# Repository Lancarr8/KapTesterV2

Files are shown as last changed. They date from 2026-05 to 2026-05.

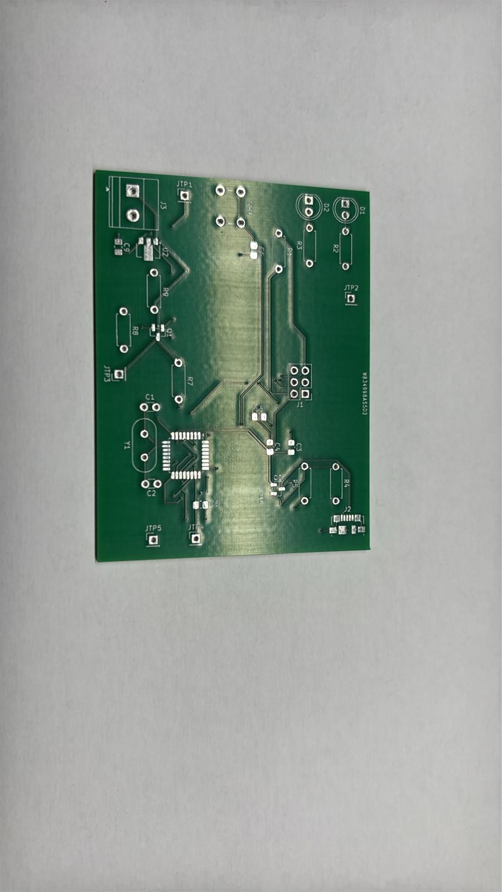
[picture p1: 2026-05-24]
Dokumente/Phasen/Durchführung/Fotos V1/V1_Leer_Front.jpeg

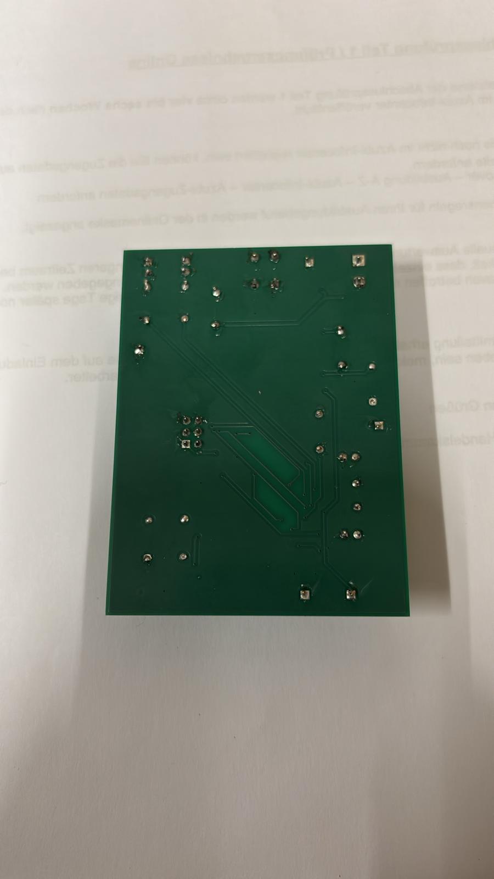
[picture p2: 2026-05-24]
Dokumente/Phasen/Durchführung/Fotos V1/V1_Back_Best.jpeg

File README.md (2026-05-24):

# ⚡ KapTester V2

> Capacitance Tester — ATmega328P based custom PCB project  
> Built as **AP2 (Abschlussprüfung Teil 2)** — Vocational exam project 🇩🇪







---

## 📷 Photos
*Coming soon – V2 build photos*

---

## 📖 About

The **KapTester V2** is a custom-built capacitance measurement device based on the ATmega328P microcontroller. It was designed and built from scratch as part of a vocational training exam (IHK AP2), covering all phases from schematic design to PCB manufacturing and firmware development.

---

## ⚙️ Hardware

| Component | Details |
|---|---|
| MCU | ATmega328P @ 16MHz |
| Display | SSD1306 OLED 128x64 (I2C) |
| Voltage Reg | LM317 (1.2V – 32V adjustable) |
| PCB | Custom 2-layer, manufactured by PCBWay |
| Power | USB (5V) |
| Interface | Tactile button, screw terminals |

---

## 💾 Firmware

Three firmware versions were developed during the project:

| Version | Folder | Description |
|---|---|---|
| FW1 | `fw1_produktion` | Production firmware – stable release |
| FW2 | `fw2_test` | Test firmware – debugging & measurement testing |
| FW3 | `fw3_Voll` | Full feature firmware – all functions enabled |

### 🔧 Flashing

```bash
# Flash production firmware via avrdude
avrdude -c usbasp -p m328p -U flash:w:fw1_produktion/kaptester.hex:i
```

---

## 📁 Repository Structure

```
KapTesterV2/
├── Firmware/
│   ├── fw1_produktion/     # Production firmware (main.c, .hex, .elf)
│   ├── fw2_test/           # Test firmware
│   └── fw3_Voll/           # Full firmware
├── KiCad KapTester V2/
│   ├── KapTesterV2.kicad_sch   # Schematic
│   ├── KapTesterV2.kicad_pcb   # PCB layout
│   └── GerberV2/               # Gerber files for manufacturing
├── Dokumente/              # Project documentation (German)
│   └── Phasen/             # Phase documentation (Info/Plan/Build/Evaluate)
└── Präsentation/           # Final exam presentation (PPTX + PDF)
```

---

## 🛠️ Tools Used

- **AVR-GCC** – Firmware compilation
- **avrdude** – Flashing
- **KiCad 8** – Schematic & PCB design
- **PCBWay** – PCB manufacturing

---

## 📄 License

MIT License – feel free to use, modify and build upon this project.

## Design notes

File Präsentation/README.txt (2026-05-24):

Infos für Vorstellung

Vorteile gegenüber DMM

Messbereich (viele DMMs messen nur bis 200 µF oder max. 2.000 µF – für 10.000 µF-Elkos reicht das nicht), 

Messgeschwindigkeit (ein DMM braucht bei großen Elkos 30+ Sekunden und gibt oft keinen stabilen Wert – dein Gerät hat einen deterministischen Ablauf mit max. 15 s Timeout),

Sicherheit (automatischer Entladepfad, Verpolschutz, dediziertes Gerät für diese Aufgabe). Der KapTester ist ein schnelles Werkstatt-Prüfmittel für grobe Pass/Fail-Entscheidungen – kein Präzisionsgerät.

Eingangsspannung Facts

Micro-USB ist weit verbreitet, jeder hat ein passendes Kabel

Durch die Bauform ist eine Verpolung beim Einstecken nicht möglich

D+/D−-Datenleitungen sind bei mir no-connect – ich nutze den USB-Anschluss ausschließlich als Spannungsversorgung.

5V USB ist ein standardisierter Pegel, der alle Komponenten meiner Schaltung versorgen kann. 
(Der ATmega328P arbeitet von 1,8V bis 5,5V, der LM317L braucht mindestens ~2,5V Eingangsspannung um seinen Dropout zu überwinden, und das OLED läuft auf 3,3–5V. USB liefert bis zu 500 mA – meine Schaltung braucht maximal ~50 mA, also mehr als ausreichend)

Nach der 5V Eingangsspannung ->  Q1 – der PMOS Verpolschutz

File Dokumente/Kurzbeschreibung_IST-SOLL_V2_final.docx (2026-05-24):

Kurzbeschreibung des betrieblichen Auftrags und der Anlage

Kapazitätstester (KapTester V2) │ AP2 2026

Projektbezeichnung | Kapazitätstester – Betrieblicher Auftrag AP2
Azubi / Ersteller | Nico Schmidt
Ausbildungsberuf | Elektroniker für Geräte und Systeme
Bearbeitungszeitraum | März 2026 – Mai 2026
Dokumentversion | V2.0 │ Stand 26.04.2026

1 IST-Zustand und SOLL-Zustand

IST-Zustand (Problem) | SOLL-Zustand (Ergebnis)
Fehlende Prüfmöglichkeit im Werkstattbetrieb: Elektrolytkondensatoren lassen sich nicht schnell auf Kapazitätswert prüfen. Handelsübliche Multimeter sind im Bereich > 1.000 µF ungenau oder fehlen. Beim Umgang mit geladenen Großkondensatoren (bis 10.000 µF) besteht Sicherheitsrisiko durch Restladung und Verpolung. Kein dediziertes Prüfmittel im Ausbildungsbetrieb vorhanden. | Eigenentwickelter Kapazitätstester (Prototyp V2): Messbereich 10 µF – 10.000 µF · Genauigkeit ±20 % Messprinzip: Konstantstromladung (LM317L, 1,042 mA) + ATmega328P-AU ADC mit interner 1,1-V-Referenz Schutz: PMOS Verpolschutz (IRLML6402, Gate 1 MΩ/100 kΩ) + gesteuerter Entladepfad (2N7002 + 470 Ω) Anzeige: 2 LEDs (OK/Fehler) + OLED SSD1306 (I²C) Platine: 2-lagig, 90×70 mm, PCBWay, Hybrid THT/SMD

2 Abgrenzung (Nicht-Ziele)

· Keine ESR-Messung (Äquivalent Series Resistance)

· Keine Leckstrommessung als eigener Messwert

· Kein Gehäuse – Prototyp als nackte Leiterplatte

· Keine Kalibrierung mit externem Referenznormal

· Kein serieller Ausgang (UART/USB-CDC)

KapTester V2 · Nico Schmidt · IHK Osnabrück · AP2 2026

Dokumentenübersicht – Anlagen zur Dokumentation

Nr. | Phase | Anlage | Zweck / Inhalt
1 | Information | Lastenheft V2.0 | Anforderungen, Funktionsumfang, Abnahmekriterien
2 | Information | Blockschaltbild (draw.io) | Systemarchitektur, Signal- und Messpfad
3 | Information | Schaltplanauszug V2 (KiCad PDF) | Vollständiger Stromlaufplan, Netze, Bauteilwerte
3,5 | Information | Techn. Schaltungsbeschreibung | Technische Schaltungsbeschreibung (Zusatz)
4 | Planung | Ablaufplan (Schritte 1–21) | Zeitplanung, Vorgehen, Meilensteine
5 | Planung | Bauteilauswahl / BOM V2 | Materialbestellung, Footprints, Lieferanten
6 | Planung | Schnittstellentabelle V2 | Alle Stecker, Testpunkte, Netzzuordnung
7 | Planung | Risikoanalyse (R1–R6) | Risiken und Gegenmaßnahmen
8 | Durchführung | Löt- und Montageprotokoll | Bestückungsreihenfolge, Nacharbeit
9 | Durchführung | Fotos Bestückung V2 | Bildnachweis Lötergebnis
10 | Bewertung | Inbetriebnahmeprotokoll | Spannungen, Ströme, Erstfunktion
11 | Bewertung | Messprotokoll | 5 Referenzkondensatoren ±20 %-Nachweis
12 | Bewertung | Abnahmeprotokoll | Übergabe, Testfälle abgehakt
13 | Bewertung | Bedienungsanleitung | Benutzerführung, Sicherheitshinweise
14 | Extras | Datenblätter, eigene Dokumente | Datenblätter, eigene Dokumente

KapTester V2 · Nico Schmidt · IHK Osnabrück · AP2 2026

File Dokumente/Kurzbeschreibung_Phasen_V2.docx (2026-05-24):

Kurzbeschreibung der Phasen

KapTester V2 │ AP2 2026 │ Nico Schmidt

Dieser Abschnitt beschreibt die vier Projektphasen (Information, Planung, Durchführung, Bewertung) des betrieblichen Auftrags AP2 – Kapazitätstester V2.

Phase 1: Information

In der Informationsphase wurden die Anforderungen des Auftrags aufgenommen und das technische Konzept erarbeitet. Ausgangspunkt war der Bedarf im Ausbildungsbetrieb: Elektrolytkondensatoren bis 10.000 µF sollen schnell und sicher auf ihre Kapazität geprüft werden können, ohne dass ein teures Laborgerät erforderlich ist.

Das Messprinzip wurde auf Basis verfügbarer Bauteile gewählt: Konstantstromladung mit dem LM317L (I = 1,042 mA) und anschließende ADC-Zeitmessung durch den ATmega328P-AU mit interner 1,1-V-Referenz. Dieses Verfahren liefert bei konstantem Strom eine lineare Spannungsrampe am Kondensator, woraus die Kapazität direkt berechnet werden kann: C = I × t / U.

Parallel wurde die Systemarchitektur in einem Blockschaltbild dokumentiert und alle Schnittstellen definiert. Als kritische Designentscheidungen wurden der PMOS-Verpolschutz (IRLML6402) und der gesteuerte Entladepfad (2N7002) identifiziert.

· Lastenheft V2 mit MUSS/SOLL/KANN-Anforderungen und Abnahmekriterien erstellt

· Blockschaltbild mit allen Signalpfaden (Power, Messpfad, Steuerpfad) erstellt

· Technische Schaltungsbeschreibung aller 14 Funktionsblöcke erstellt

· Schaltplanauszug V2 (KiCad) als Nachweis beigefügt

✓ Messprinzip festgelegt: Konstantstromladung + ADC-Zeitmessung

✓ Systemarchitektur dokumentiert, alle Netze benannt

✓ Anforderungen messbar und prüfbar im Lastenheft formuliert

Phase 2: Planung

Die Planungsphase umfasste die vollständige Vorbereitung der Fertigung: Bauteilauswahl, Risikoanalyse, Schaltplanerstellung und PCB-Layout. Ein zentrales Ereignis in dieser Phase war das Erkennen eines kritischen Fehlers in der V1-Platine nach der Bestellung: Das verwendete KiCad-Symbol für den ATmega328P-AU war ein DIP-28-Simulationssymbol statt des TQFP-32-Symbols. Alle 32 Pins waren damit falsch verdrahtet.

Dieser Fehler (Risikoanalyse R6) wurde vollständig analysiert und durch eine komplette Neugestaltung von Schaltplan und PCB in Version 2 behoben. Gleichzeitig wurden zwei weitere Verbesserungen vorgenommen: Der Gate-Teiler des PMOS-Verpolschutzes wurde von 100 kΩ/100 kΩ auf 1 MΩ/100 kΩ geändert (VGS von −2,5 V auf −4,5 V verbessert), und ein Entladestrombegrenzer R20 (470 Ω) wurde in Serie mit dem 2N7002-Drain eingefügt, um thermische Überlastung bei Großkondensatoren zu verhindern (Risikoanalyse R7).

· Ablaufplan mit 21 Schritten erstellt, V2-Änderungen dokumentiert

· BOM V2 vollständig mit Footprints, Lieferanten und Bestellstatus

· Schnittstellentabelle: alle 16 Netze, 4 externe Stecker, 10 Testpunkte

· Risikoanalyse R1–R7 mit Ursache, Auswirkung, Maßnahme und Nachweis

· V2-PCB (90×70 mm, 2-lagig, DRC = 0 Fehler) bei PCBWay bestellt

✓ V1-Fehler (falsches ATmega-Symbol) erkannt, analysiert und in V2 behoben

✓ PCB V2 bestellt: 5 Stück, 90×70 mm, PCBWay, Lieferung ~30.04.2026

✓ Alle V2-Verbesserungen (R2=1MΩ, R20=470Ω) in Schaltplan und PCB eingearbeitet

Phase 3: Durchführung

Die Durchführungsphase umfasst Wareneingang, Bestückung und Löten der V2-Platine. Die Bestückungsreihenfolge folgt dem bewährten Schema: SMD-Passivteile zuerst, dann SMD-ICs (SOT-23, SOT-89), danach der TQFP-32-Mikrocontroller, zuletzt alle THT-Bauteile und Steckverbinder.

Besondere Sorgfalt gilt dem ATmega328P-AU (TQFP-32, 0,8-mm-Pinabstand): Pin 1 muss mit der Markierung auf dem Silkscreen übereinstimmen. Der Lötvorgang wird mit einer Meißelspitze bei 375 °C und No-Clean-Lot durchgeführt. Alle Lötstellen werden anschließend mit einer Lupe auf Lötbrücken, kalte Lötstellen und Pad-Schäden geprüft.

Ein weiterer wichtiger Schritt ist die Dokumentation durch Fotos: leere Platine, nach SMD-Bestückung und nach vollständiger THT-Montage. Das Lötprotokoll wird parallel zur Bestückung ausgefüllt.

· Wareneingang V2-Platinen und Bauteile (Abgleich BOM)

· Bestückung nach Lötprotokoll, 12 Schritte in festgelegter Reihenfolge

· Besondere Prüfung R20 (470 Ω) in Serie Q2-Drain – V2-Neubauteil

· Sichtprüfung nach IPC-A-610 Klasse 2 (11 Kriterien)

· Fotodokumentation: leer / nach SMD / nach THT / Gesamtansicht

✓ Platine V2 vollständig bestückt und gelötet

✓ Sichtprüfung: alle 11 Kriterien geprüft und dokumentiert

✓ Fotos der Bestückung als Anlage beigefügt

Phase 4: Bewertung

Die Bewertungsphase beinhaltet Inbetriebnahme, Funktionsprüfung und formale Übergabe. Die Inbetriebnahme erfolgt schrittweise: zuerst Kurzschlusscheck mit dem Ohmmeter (GND gegen +5V_BOARD), dann Ersteinschalten mit 5 V / 100 mA Strombegrenzung. Alle 10 Testpunkte (JTP1–JTP10) werden mit dem Digitalmultimeter vermessen und im Inbetriebnahmeprotokoll dokumentiert.

Nach erfolgreicher Inbetriebnahme werden die Fuse Bits des ATmega gesetzt (LFUSE=0xFF, HFUSE=0xD9, EFUSE=0xFF) und die Firmware über den USBasp-Programmer via J4 (AVR-ISP-6) geladen. Die Funktionsprüfung umfasst fünf Referenzkondensatoren (10 / 100 / 1.000 / 4.700 / 10.000 µF) sowie Verpoltest, Entladetest und Timeout-Test gemäß Lastenheft.

Die Abnahme gilt als erfüllt, wenn alle MUSS-Kriterien des Lastenhefts nachweisbar erfüllt sind (Messgenauigkeit ±20 %, Entladezeit < 10 s, keine Beschädigung bei Verpolung, Fehlerzustandsanzeige funktioniert).

· Inbetriebnahmeprotokoll: Kurzschlusscheck, Ersteinschalten, Testpunkte JTP1–10

· Firmware flashen: Fuse Bits + kaptester.hex via USBasp

· Messprotokoll: 5 Referenz-DUTs, Verpoltest, Entladetest, Timeout

· Abnahmeprotokoll: alle 8 Testfälle abgehakt

· Bedienungsanleitung als Übergabedokument

✓ Kapazitätsmessung 10–10.000 µF mit ±20 % Genauigkeit nachgewiesen

✓ Alle MUSS-Anforderungen des Lastenhefts erfüllt

✓ Übergabe an Ausbildungsbetrieb mit Bedienungsanleitung

KapTester V2 · Kurzbeschreibung der Phasen · Nico Schmidt · IHK Osnabrück AP2 2026

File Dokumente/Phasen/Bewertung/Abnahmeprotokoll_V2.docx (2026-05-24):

Abnahmeprotokoll

KapTester V2 │ Bewertung │ AP2 2026

Identifikation / Rückverfolgbarkeit
Protokoll-ID | NicoSchmidt-AP2-KapTester-ANP-20260523-0002-R1.0
Datum | 23.05.2026
Prüfobjekt | Kapazitätstester V2 · Seriennr. KapTester-V2-001
Revision | PCB V2.0 · Schaltplan V2.0 · FW3 (kaptesterfw3_v11.hex)
Schutzklasse | NA – SELV 5 V DC, kein Netzanschluss
Bearbeiter | Nico Schmidt

B) Lieferumfang / Übergabegegenstand
Gegenstand der Abnahme | [X] Einzelstück (Prototyp V2) [ ] Serie [ ] Reparatur
Nr. 1. | KapTester V2 – Platine bestückt (KapTester-V2-001)
Nr. 2. | Löt- und Montageprotokoll V2 (LMP-20260501-0002-R1.0)
Nr. 3. | Inbetriebnahmeprotokoll V2 (IBP-20260501-0002-R1.0)
Nr. 4. | Messprotokoll V2 (MP-20260502-0002-R1.0)
Nr. 5. | Schaltplanauszug V2 (KiCad PDF)
Nr. 6. | BOM V2 (Bauteilauswahl)
Nr. 7. | Bedienungsanleitung V2

C) Referenzdokumente / Nachweise
Dokument | Protokoll-ID | Datum | Ergebnis | Bemerkung
Löt- und Montageprotokoll | LMP-…-0002 | 27.04.2026 | Ok | korrekt
Inbetriebnahmeprotokoll | IBP-…-0002 | 27.04.2026 | Ok | Korrekt
Messprotokoll | MP-…-0002 | 27.04.2026 | Ok | Korrekt
Schaltplan V2 | KapTester-SCH-V2.0 | 27.04.2026 | NA | KiCad PDF
Fotos Bestückung V2 | – | 27.04.2026 | | -
VDE 0701/0702 | – | 27.04.2026 | NA | SELV 5 V, nicht zutreffend

D) Abnahmekriterien / Checkliste
Nr. | Kriterium | Nachweis | OK? | Bemerkung
1 | Identifikation / Labeling korrekt (Typ, SN, Revision) | Sichtprüfung | Ok | Korrekt
2 | Dokumentation vollständig (alle Anlagen gepflegt) | Kurzbeschreibung Anlagenübersicht | Ok | Vollständig
3 | Löt-/Montagequalität i.O. (Sichtprüfung bestanden) | Lötprotokoll Abschn. F | Ok | Bestanden
4 | Inbetriebnahme bestanden (JTP1–JTP10 im Soll) | Inbetriebnahmeprotokoll | Ok | Bestanden
5 | Kapazitätsmessung ±20 % für 4 Referenz-DUTs | Messprotokoll Zeilen 6–9 | Ok | Bestanden
6 | Verpolschutz aktiv (kein Schaden, Fehleranzeige) | Messprotokoll Zeile 10 | Ok | Bestanden
7 | Entladetest: < 0,1 V in ≤ 10 s (4.700 µF) | Messprotokoll Zeile 11 | Ok | Bestanden
8 | Timeout-Test: ≤ 15 s, rote LED aktiv | Messprotokoll Zeile 12 | Ok | Bestanden
9 | R20 (470 Ω) verbaut und wirksam (Q2 kalt) | Messprotokoll Zeile 13 | Ok | Bestanden
10 | Messwiederholbarkeit ≤ ±5 % (3× gleicher DUT) | Messprotokoll Zeile 14 | Ok | Bestanden
11 | Sicherheit: SELV 5 V, kein Netzanschluss | NA – keine VDE-Prüfpflicht | NA | Korrekt
12 | Lieferumfang vollständig (Abschnitt B) | Übergabeliste | Ok | Vollständig

E) Gesamtentscheid / Freigabe
Ergebnis | [x] Abgenommen [ ] Abgelehnt [ ] Bedingt abgenommen(Auflagen siehe F)
Bemerkung
Bearbeiter / Datum | Nico Schmidt · 27.04.2026

KapTester V2 · Abnahmeprotokoll V2 · Nico Schmidt · IHK Osnabrück AP2 2026

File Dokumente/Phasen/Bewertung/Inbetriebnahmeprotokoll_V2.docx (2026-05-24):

Inbetriebnahmeprotokoll

KapTester V2 │ Bewertung │ AP2 2026

Identifikation / Rückverfolgbarkeit
Protokoll-ID | NicoSchmidt-AP2-KapTester-IBP-20260523-0002-R1.0
Datum | 23.05.2026
Gerät / Objekt | Kapazitätstester V2 (Prototyp)
Seriennr. / Ident-Nr. | KapTester-V2-001
Revision PCB / Plan / FW | PCB V2.0 · Schaltplan V2.0 · FW3 (kaptesterfw3_v11.hex)
Schutzklasse | NA – Baugruppe ohne Gehäuse, SELV 5 V DC
Bearbeiter | Nico Schmidt

B) Rahmenbedingungen / Sicherheit
Versorgung | [X] DC/SELV [ ] AC-Netz [ ] Batterie
Nennwerte | 5 V DC · Stromlimit 200 mA (am Netzteil einstellen)
Einschaltmethode | [X] DC-Netzteil mit Strombegrenzung
ESD | ESD-Matte + Armband gemäß IEC 61340-5-1
Abbruchkriterien | Ungewöhnliche Erwärmung · Geruch / Rauch · Strom > 200 mA · Sichtbarer Schaden

C) Vorprüfungen (spannungsfrei)
Sichtprüfung | [x] Lötprotokoll bestanden · [x] keine Lötbrücken · [x] Polung D1/D2/U1 korrekt
Kurzschlusscheck | DMM Ohm: GND ↔ +5V_BOARD → Soll: > 500 Ω · Gemessen: _____ Ω
Mechanische Kontrolle | [x] J3 gerade und fest · [x] J1 USB verankert · [x] keine Fremdkörper

D) Messmittel
Multimeter | UNI-T UT139C · [x] kalibriert · [ ] Werkszustand
Netzteil | Jedes beliebige · Strombegrenzung einstellbar

Nr. | Prüfschritt | Art | Soll / Grenzwert | Ist-Wert | OK? | Bemerkung
1 | Sichtprüfung Bestückung | visuell | Keine Lötbrücken, Polung korrekt | | Ok | Korrekt und sauber
2 | Kurzschlusscheck GND ↔ +5V_BOARD | elektr. | Soll > 500 Ω | ___ Ω | | Lötprotokoll Abschn. F
3 | Netzteil konfigurieren (5 V / 200 mA Limit) | elektr. | 5,00 V eingestellt | ___ V | | Vor Einschalten prüfen
4 | Ersteinschalten – Strom beobachten | elektr. | < 100 mA Ruhestrom | ___ mA | | Abbruch bei > 200 mA
5 | JTP1: USB_5V messen | elektr. | 4,80 – 5,20 V | ___ V | | DMM an JTP1/JTP5
6 | JTP2: +5V_BOARD messen | elektr. | 4,80 – 5,20 V (Δ ≤ 50 mV zu JTP1) | ___ V | | Q1 muss durchschalten
7 | JTP4: LM317_OUT messen (Leerlauf) | elektr. | ≈ 4,5 V (kein DUT) | ___ V | | LM317 aktiv
8 | JTP7: AVCC messen | elektr. | 4,80 – 5,20 V (≈ JTP2) | ___ V | | ADC-Versorgung
9 | JTP8: RESET messen (Ruhezustand) | elektr. | ≈ 5 V (HIGH) | ___ V | | C-Kondensator prüfen
10 | JTP10: DISCH_GATE messen (Ruhe) | elektr. | < 0,1 V (LOW, R9 zieht nach GND) | ___ V | | Q2 muss gesperrt sein
11 | D1 (grüne LED) leuchtet nach Einschalten | visuell | Grüne LED leuchtet | | | LED_PWR aktiv
12 | SW1 drücken – Reaktion prüfen | visuell | Messung startet (LED-Wechsel oder Reaktion) | | | Firmware nötig

E) Gesamtergebnis
Inbetriebnahme | [x] Bestanden [ ] Nicht bestanden [ ] Bestanden mit Abweichung
Freigabe für Messprotokoll | [x] Ja [ ] Nein (Abweichungen zuerst beheben)
Bemerkung

F) Freigabe
Rolle | Name | Datum | Unterschrift
Bearbeiter | Nico Schmidt | 27.04.2026

KapTester V2 · Inbetriebnahmeprotokoll V2 · Nico Schmidt · IHK Osnabrück AP2 2026

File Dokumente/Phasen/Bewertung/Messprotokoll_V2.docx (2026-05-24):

Messprotokoll

KapTester V2 │ Bewertung │ AP2 2026

Identifikation / Rückverfolgbarkeit
Protokoll-ID | NicoSchmidt-AP2-KapTester-MP-20260523-0002-R1.0
Datum | 23.05.2026
Gerät / Objekt | Kapazitätstester V2 (Prototyp)
Seriennr. | KapTester-V2-001
Revision | PCB V2.0 · Schaltplan V2.0 · FW3 (kaptesterfw3_v11.hex)
Bearbeiter | Nico Schmidt
Umgebung | Temp: 21 °C · Werkstatt / Labor

B) Prüfumfang / Messbedingungen
Prüfart | [X] Elektrische Messung [X] Funktionstest [X] Kapazitätsmessung
Versorgung | 5 V DC, USB Micro-B (Laptop oder Netzteil ≥ 500 mA)
Akzeptanzkriterien | Gemäß Lastenheft V2.0: Kapazität ±20 %, Entladezeit ≤ 10 s, Verpolschutz aktiv
Messmittel | UNI-T UT139C · Referenzkondensatoren:

Nr. | Messpunkt / Signal | Methode | Soll (±Tol.) | Ist-Wert | Einheit | OK? | Bemerkung

Versorgung & Ruhezustand
1 | USB_5V (JTP1) | DMM | 4,80 – 5,20 V | | V
2 | +5V_BOARD (JTP2) | DMM | 4,80 – 5,20 V | | V | | Q1 PMOS muss leiten
3 | AVCC (JTP7) | DMM | ≈ +5V_BOARD | | V | | ADC-Versorgung
4 | DISCH_GATE (JTP10) Ruhe | DMM | < 0,10 V (LOW) | | V | | Q2 gesperrt
5 | LM317_OUT (JTP4) Leerlauf | DMM | ≈ 4,5 V | | V | | Kein DUT

Kapazitätsmessung – 5 Referenz-DUTs (±20 %)
6 | DUT: 100 µF Referenz | Messung | 80 – 120 µF | | µF | | 3× messen, Mittelwert
6b | Wiederholung 2 | Messung | 80 – 120 µF | | µF
7 | DUT: 1.000 µF Referenz | Messung | 800 – 1.200 µF | | µF
7b | Wiederholung 2 | Messung | 800 – 1.200 µF | | µF
8 | DUT: 4.700 µF Referenz | Messung | 3.760 – 5.640 µF | | µF
8b | Wiederholung 2 | Messung | 3.760 – 5.640 µF | | µF
9 | DUT: 10.000 µF Referenz | Messung | 8.000 – 12.000 µF | | µF
9b | Wiederholung 2 | Messung | 8.000 – 12.000 µF | | µF

Funktionstests
10 | Verpoltest: DUT verpolt anschließen | visuell | Rote LED, keine Erwärmung, Messung blockiert | | – | | Lastenheft R3
11 | Entladetest: 4.700 µF nach Messung | DMM | < 0,10 V in ≤ 10 s | ___ V / ___ s | V/s | | JTP9 = MEAS_NODE
12 | Timeout-Test: kein DUT angeschlossen | visuell | Rote LED + OLED-Fehler in ≤ 15 s | | – | | Lastenheft MUSS-7
13 | Entladewiderstand R20: Q2 kalt nach Test | visuell/therm. | Q2 nicht warm nach 5× Entladezyklus | | – | | R20 = 470 Ω wirksam
14 | Messwiederholbarkeit: 3× gleicher DUT | Rechnung | Streuung aller 3 Messungen ≤ ±5 % relativ | | % | | Aus Zeilen 6–9

Gesamtergebnis
Ergebnis | [x] Bestanden [ ] Nicht bestanden [ ] Bestanden mit Abweichung
Begründung | -
Bearbeiter / Datum | Nico Schmidt · 27.04.2026

KapTester V2 · Messprotokoll V2 · Nico Schmidt · IHK Osnabrück AP2 2026

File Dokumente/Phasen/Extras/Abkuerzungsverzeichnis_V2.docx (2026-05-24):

Abkürzungsverzeichnis

KapTester V2 │ AP2 2026 │ Nico Schmidt

Alle in der Projektdokumentation verwendeten Abkürzungen, Netznamen und Fachbegriffe in alphabetischer Gruppenreihenfolge.

Abkürzung / Begriff | Bedeutung / Erklärung | Kontext / Vorkommen

A · Allgemein / Projekt
AP2 | Abschlussprüfung Teil 2 (IHK) | Prüfungskontext
BOM | Bill of Materials – Stückliste aller Bauteile | Planung, KiCad
DRC | Design Rule Check – automatische Prüfung des PCB-Layouts | KiCad PCB
DUT | Device Under Test – das zu prüfende Bauteil (hier: Kondensator) | Schaltplan, Protokolle
ERC | Electrical Rules Check – Prüfung des Schaltplans auf Fehler | KiCad Schematic
IHK | Industrie- und Handelskammer | Prüfungskontext
IST | Aktueller Zustand (Ausgangssituation) | Kurzbeschreibung
SOLL | Zielzustand (Ergebnis) | Kurzbeschreibung
THT | Through-Hole Technology – bedrahtete Bauteile | Bestückung, BOM
SMD | Surface-Mounted Device – oberflächenmontierte Bauteile | Bestückung, BOM

B · Elektronik / Schaltung
ADC | Analog-to-Digital Converter – Analog-Digital-Wandler | ATmega, Messung
ADC0 | Kanal 0 des ADC (ATmega-Pin PC0) | Schaltplan, Firmware
AVCC | Analoge Versorgungsspannung des ADC (ATmega-Pin 18) | Schaltplan
ESR | Equivalent Series Resistance – Reihenwiderstand eines Kondensators (nicht gemessen) | Lastenheft
MOSFET | Metal-Oxide-Semiconductor Field-Effect Transistor – Feldeffekttransistor | Schaltplan
NMOS / N-MOSFET | N-Kanal MOSFET (low-side Schalter, z. B. Entladepfad Q2) | Q2 / 2N7002
PMOS / P-MOSFET | P-Kanal MOSFET (high-side Schalter, z. B. Verpolschutz Q1) | Q1 / IRLML6402
PWM | Pulse Width Modulation – Pulsweitenmodulation (hier nicht genutzt) | Allgemein
RC-Filter | R1 / ADC ESD-Schutz | R1
SELV | Safety Extra Low Voltage – Schutzkleinspannung (hier: 5 V DC) | Protokolle
SPI | Serial Peripheral Interface – serieller Bus (für ISP-Programmierung) | ISP, Firmware
TQFP | Thin Quad Flat Package – Gehäuseform des ATmega328P-AU (32-polig, 7×7 mm) | U1, BOM
VGS | Gate-Source-Spannung am MOSFET (bestimmt Leitfähigkeit) | Q1 Analyse

C · Netznamen (Schaltplan V2)
+5V_BOARD | Interne 5-V-Versorgung nach Verpolschutz Q1 | Schaltplan, alle Module
ADC_MEAS | Gefiltertes Messsignal am ADC-Eingang (nach R1+C8) | Schaltplan, Messpfad
DISCH_GATE | Digitales Steuersignal ATmega → Gate Q2 (Entladung ein/aus) | Schaltplan, Firmware
GND | Masse / 0-V-Bezugspotenzial | Alle Module
I2C_SCL | I²C Taktleitung (ATmega PC5 → J2/OLED) | Schaltplan, OLED
I2C_SDA | I²C Datenleitung (ATmega PC4 → J2/OLED) | Schaltplan, OLED
LED_ERR | Fehler-LED-Signal (rote LED D2, ATmega PD3) | Schaltplan
LED_PWR | Betriebs-LED-Signal (grüne LED D1, ATmega PD2) | Schaltplan
LM317_OUT | Ausgang des LM317 (Konstantstrom-Ausgangspunkt) | Schaltplan, JTP4
MEAS_NODE | Messknoten = DUT+ = Ladepunkt = Entladepunkt | Schaltplan, alle
MISO | Master In Slave Out – ISP-Datenleitung (ATmega → Programmer) | J4, ISP
MOSI | Master Out Slave In – ISP-Datenleitung (Programmer → ATmega) | J4, ISP
RESET | Reset-Signal ATmega (aktiv LOW, ISP-Programmierung) | J4, ISP
SCK | Serial Clock – ISP-Taktsignal | J4, ISP
START_BTN | Start-Taster-Signal (ATmega PC2, Pull-Up R10) | Schaltplan
USB_5V | 5-V-Versorgung direkt von USB VBUS (vor Verpolschutz Q1) | Schaltplan, JTP1
VBUS | USB-Versorgungsleitung (Standard USB-Bezeichnung, 5 V) | J1, USB

D · Kommunikation / Protokolle
I²C | Inter-Integrated Circuit – 2-Leiter-Seriellbus (SDA + SCL) für OLED | J2, Firmware
ISP | In-System Programming – Firmware-Programmierung im eingebauten Zustand | J4, avrdude
OLED | Organic Light Emitting Diode – hier: 0,96"-Display SSD1306 | J2, Firmware
SSD1306 | Controller-IC des OLED-Displays (I²C-Adresse 0x3C) | J2
UART | Universal Asynchronous Receiver/Transmitter – seriell (hier nicht genutzt) | Nicht implementiert
USB | Universal Serial Bus – hier: Versorgungseingang 5 V | J1

E · Qualität / Normen / Protokolle
ANP | Abnahmeprotokoll | Bewertung
IBP | Inbetriebnahmeprotokoll | Bewertung
IPC-A-610 | Norm für Lötqualität: Kl. 1=Consumer, Kl. 2=Industrie, Kl. 3=High-Rel. | Lötprotokoll
LMP | Löt- und Montageprotokoll | Durchführung
MP | Messprotokoll | Bewertung
NA | Not Applicable – nicht zutreffend (Prüfpunkt entfällt) | Alle Protokolle
NOK | Not OK – Kriterium nicht erfüllt | Alle Protokolle
OK | Kriterium erfüllt | Alle Protokolle
PAO | Projektantrag/Auftrag-Objekt (IHK-Antragsformular) | Deckblatt
SELV | Safety Extra Low Voltage – Schutzkleinspannung ≤ 50 V DC | Protokolle, SK III
SK I/II/III | Schutzklasse I (PE), II (Doppeliso.), III (SELV) | Protokolle

F · Bauteile (Referenzbezeichnungen V2)
C1–C5, C8 | Abblockkondensatoren SMD 0805 (100 nF) und Entpreller (10 nF) | Schaltplan
C6, C7 | Quarz-Lastkondensatoren THT 22 pF | Y1 / Taktgenerator
D1 | LED grün 5 mm – Betriebsanzeige (LED_PWR) | Schaltplan
D2 | LED rot 5 mm – Fehleranzeige (LED_ERR) | Schaltplan
J1 | USB Micro-B Buchse (Molex 47346-0001) – Versorgungseingang | Schaltplan
J2 | 4-poliger PinHeader P2.54 – OLED-Anschluss (GND/VCC/SCL/SDA) | Schaltplan
J3 | Schraubklemme Phoenix MKDS P5.08 – DUT-Anschluss | Schaltplan
J4 | AVR-ISP-6 Header 2×3 P2.54 – ISP-Programmierung | Schaltplan
JTP1–10 | Testpunkte 1×1 P2.54 (USB5V/5VBOARD/SDA/LM317IN/GND/ADC/AVCC/RESET/MEAS/DISCH) | Schaltplan
Q1 | IRLML6402 – PMOS Verpolschutz (SOT-23) | Schaltplan
Q2 | 2N7002 – NMOS Entladeschalter (SOT-23) | Schaltplan
R1 | 1 kΩ SMD – ADC ESD-Schutz (in Serie) | Schaltplan
R2 | 1 MΩ MELF – Gate-Teiler Q1 (nach +5V) – V2-Änderung | Schaltplan
R3 | 100 kΩ MELF – Gate-Teiler Q1 (nach GND) | Schaltplan
R4, R5 | 4,7 kΩ 0805 – I²C Pull-Up SDA/SCL | Schaltplan
R6, R7 | 330 Ω MELF – LED-Vorwiderstände D2/D1 | Schaltplan
R8 | 1,2 kΩ THT – LM317 Setwiderstand (I = 1,042 mA) | Schaltplan
R9 | 100 kΩ THT – Gate-Pull-Down Q2 (DISCH_GATE LOW im Ruhezustand) | Schaltplan
R10 | 10 kΩ THT – START_BTN Pull-Up | Schaltplan
R20 | 470 Ω 0805 – Entlade-Schutzwiderstand Q2-Drain – V2-Neu | Schaltplan
SW1 | Taster 6×6 mm H5 mm – Start-Taster | Schaltplan
U1 | ATmega328P-AU TQFP-32 – Mikrocontroller | Schaltplan
U2 | LM317L SOT-89 – Konstantstromquelle | Schaltplan
Y1 | 16-MHz-Quarz HC-49/U – Taktgenerator | Schaltplan

KapTester V2 · Abkürzungsverzeichnis · Nico Schmidt · AP2 2026

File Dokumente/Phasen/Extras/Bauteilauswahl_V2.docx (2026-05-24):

Bauteilauswahl – Entscheidung & Begründung

KapTester V2 │ Planung │ AP2 2026

Für das Projekt wird ein Hybrid-Layout (THT/SMD) festgelegt, das handlötbar, mechanisch robust und messstabil ist. Ab diesem Punkt werden Footprints nicht mehr geändert, außer bei zwingenden Verfügbarkeits- oder Kollisionsproblemen.

1 Designprinzip: THT/SMD-Hybrid

THT wird dort eingesetzt, wo mechanische Belastbarkeit und Handlötbarkeit im Vordergrund stehen – also bei Steckverbindern, Bedienelementen und Bauteilen die oft berührt werden. SMD wird gezielt dort eingesetzt, wo kurze Leitungswege die Messqualität verbessern, insbesondere im ADC-Umfeld und bei den Abblockkondensatoren direkt an den MCU-Versorgungspins.

2 Bauteilentscheidungen nach Baugruppe

Ref. | Funktion | Bauteil / Typ | Gehäuse | Begründung der Wahl

Aktive Bauteile
U1 | Mikrocontroller | ATmega328P-AU | TQFP-32 7×7mm | Bekannte Plattform, ADC + Timer intern, ISP-programmierbar, gut dokumentiert
U2 | Konstantstromquelle | LM317L | SOT-89-3 | Kompakt, stabil, liefert präzise 1,042 mA über R8=1,2kΩ
Q1 | Verpolschutz | IRLML6402 | SOT-23 | PMOS, R_DS(on) < 65 mΩ, geringe Verluste, VGS = −4,5 V mit 1MΩ/100kΩ-Teiler
Q2 | Entladepfad | 2N7002 | SOT-23 | NMOS, geringe Verluste, bewährt, Gate-Pull-Down R9 verhindert ungewolltes Einschalten
Y1 | Taktgenerator | 16 MHz HC-49/U | THT vertikal | Standard, passt zur ATmega-Fuse-Konfiguration LFUSE=0xFF

Steckverbinder / Mechanik
J1 | USB-Versorgung | Molex 47346-0001 | USB Micro-B THT | 4 THT-Lötanker, mechanisch stabil gegen Kabelzug, belasteter Anschluss
J2 | OLED-Anschluss | PinHeader 1×4 | THT P2.54 | Standardraster, steckbar, servicefreundlich, klare Pinbeschriftung möglich
J3 | DUT-Anschluss | Phoenix MKDS-1,5-2 | THT P5.08 | Robuster Industriestandard, sicherer Kontakt für Großelkos im Werkstattbetrieb
J4 | ISP-Programmierung | PinHeader 2×3 | THT P2.54 | Standardraster für USBasp, gut steckbar, Pin-1-Markierung auf Silkscreen
SW1 | Start-Taster | 6×6 mm Taster H5mm | THT | Standard, robust, gut bedienbar ohne Gehäuse, mechanisch stabil
D1/D2 | LEDs Betrieb/Fehler | LED 5 mm grün/rot | THT | Hohe Sichtbarkeit bei Vorführung/Prüfung, robuste Bauform

Widerstände
R1 | ADC ESD-Schutz | 1 kΩ | THT DIN0207 | In Serie vor ADC, kurzer Weg, THT austauschbar
R2 | Gate-Teiler Q1 | 1 MΩ | MELF MMB-0207 | V2: 1MΩ statt 100kΩ → VGS = −4,5V, robusteres Einschalten
R3 | Gate-Teiler Q1 | 100 kΩ | MELF MMB-0207 | Mit R2: V_Gate ≈ 0,45V → VGS ≈ −4,55V
R4/R5 | I²C Pull-Up | 4,7 kΩ | SMD 0805 | I²C-Bus Pull-Up SDA/SCL → kurze Wege zum ATmega
R6/R7 | LED-Vorwiderstände | 330 Ω | MELF MMB-0207 | I_LED = (5V−2V)/330Ω ≈ 9mA, gut sichtbar
R8 | LM317 Setwiderstand | 1,2 kΩ | THT DIN0207 | I = 1,25V/1200Ω = 1,042mA, THT für einfachen Austausch
R9 | Gate-Pull-Down Q2 | 100 kΩ | THT DIN0207 | Hält DISCH_GATE bei tristatetem ATmega sicher LOW
R10 | START_BTN Pull-Up | 10 kΩ | THT DIN0207 | Definierter HIGH-Pegel an PC2, extern robuster als interner Pull-Up
R20 | Entlade-Schutz Q2 | 470 Ω | SMD 0805 | V2-Neu: Strombegrenzer Q2-Drain, schützt Q2 bei Großelkos

Kondensatoren
C1–C5 | VCC-Abblockkondensatoren | 100 nF | SMD 0805 | Direkt an MCU-Versorgungspins → kürzeste Wege → beste Entkopplung
C6/C7 | Quarz-Lastkondensatoren | 22 pF | THT Disc P2.50 | Beide direkt an XTAL1/XTAL2, kurze GND-Verbindung
C8 | SW1-Entpreller | 10 nF | SMD 0805 | Parallel zu SW1, filtert Prellimpulse

3 Footprint-Freeze – Warum?

· Verhindert mechanische Fehlpassung (USB/Taster/Klemme/Header) und Layout-Rework kurz vor Bestellung

· Macht BOM, Layout und Beschaffung konsistent

· Reduziert Risiko von Kollisionen und Gerber-Fehlern

· V2-Lektion: Der DIP-28/TQFP-32-Fehler in V1 war ein Symbol-Problem – Footprint war korrekt. Trotzdem gilt: Symbol + Footprint + Datenblatt immer zusammen prüfen, bevor bestellt wird.

KapTester V2 · Bauteilauswahl V2 · Nico Schmidt · IHK Osnabrück AP2 2026

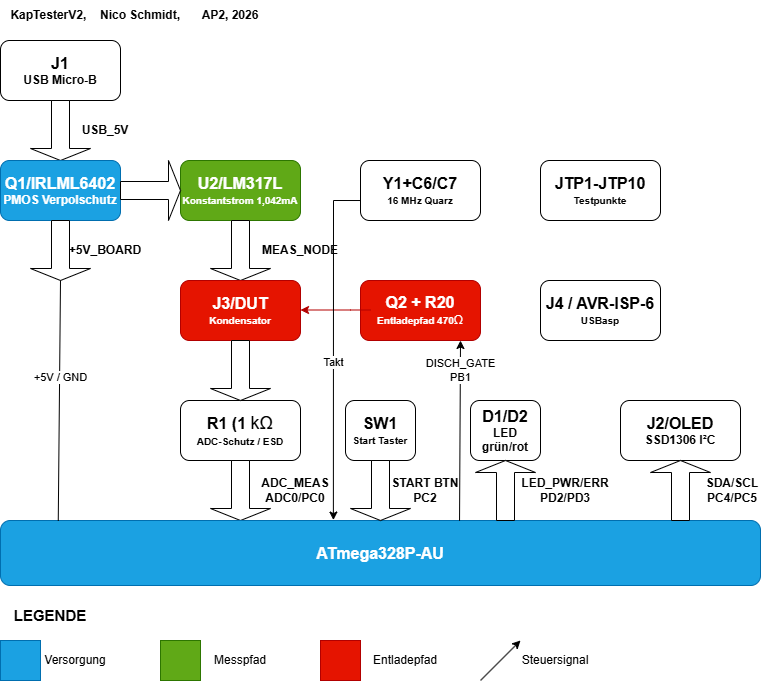
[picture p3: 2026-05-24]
Dokumente/Phasen/Information/Blockschaltbild V2.png

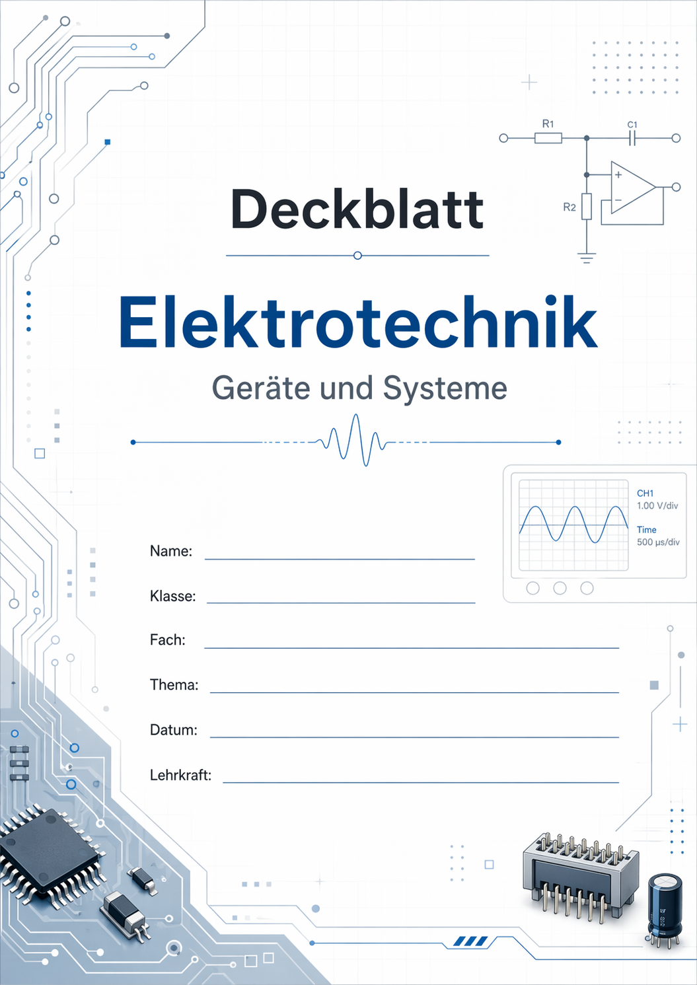
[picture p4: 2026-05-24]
Dokumente/Deckblatt.png

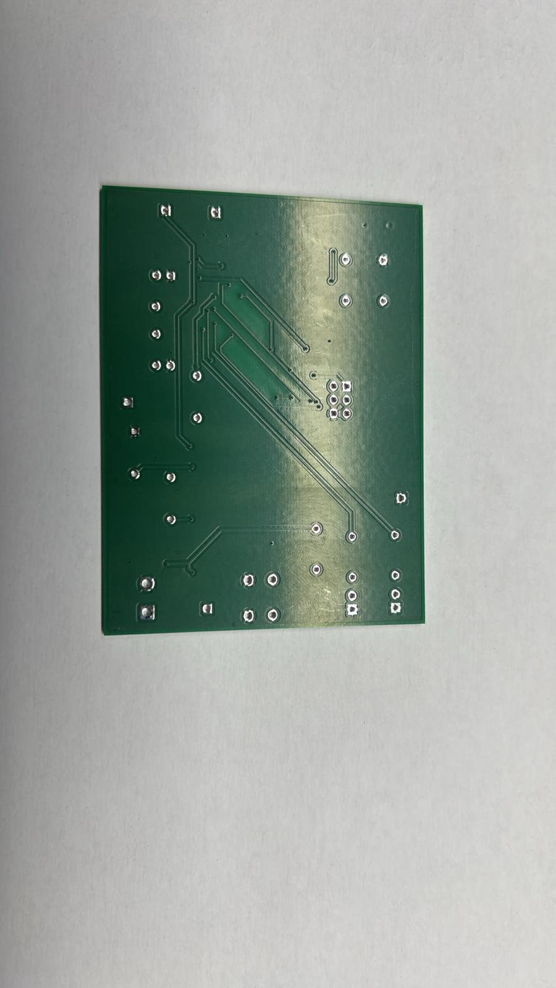
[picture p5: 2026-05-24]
Dokumente/Phasen/Durchführung/Fotos V1/V1_LEER_Back.jpeg

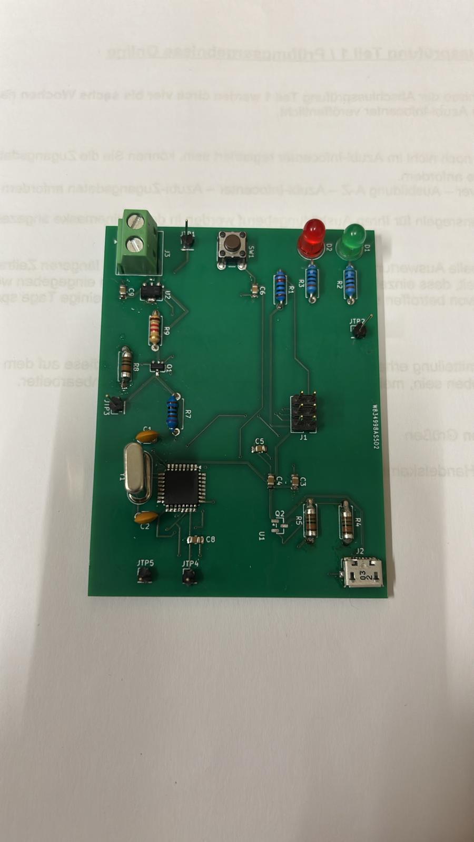
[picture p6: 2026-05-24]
Dokumente/Phasen/Durchführung/Fotos V1/V1_Front_Best.jpeg

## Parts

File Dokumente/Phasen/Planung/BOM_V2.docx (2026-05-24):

Bauteilauswahl / BOM V2

KapTester V2 │ Planung │ AP2 2026

Alle Bauteilwerte entsprechen dem Schaltplan V2 (KiCad, Stand 26.04.2026).

Ref. | Menge | Wert / Typ | Gehäuse | Beschaffung | Bemerkung

ICs / Aktive Bauteile
U1 | 1 | ATmega328P-AU | TQFP-32 7×7mm P0.8mm | bereits da | Microchip
U2 | 1 | LM317L | SOT-89-3 | bereits da | Konstantstromquelle
Q1 | 1 | IRLML6402 | SOT-23 | bereits da | PMOS Verpolschutz
Q2 | 1 | 2N7002 | SOT-23 | bereits da | NMOS Entladepfad

Widerstände
R1 | 1 | 1 kΩ | THT DIN0207 P7.62 | bereits da | ADC ESD-Schutz (in Serie)
R2 | 1 | 1 MΩ | MELF MMB-0207 | bereits da | Gate-Teiler Q1 (nach +5V)
R3 | 1 | 100 kΩ | MELF MMB-0207 | bereits da | Gate-Teiler Q1 (nach GND)
R4, R5 | 2 | 4,7 kΩ | SMD 0805 | bereits da | I²C Pull-Up SDA/SCL
R6, R7 | 2 | 330 Ω | MELF MMB-0207 | bereits da | LED-Vorwiderstände D2/D1
R8 | 1 | 1,2 kΩ | THT DIN0207 P7.62 | bereits da | LM317 Setwiderstand
R9 | 1 | 100 kΩ | THT DIN0207 P7.62 | bereits da | Gate-Pull-Down Q2
R10 | 1 | 10 kΩ | THT DIN0207 P7.62 | bereits da | START_BTN Pull-Up
R20 | 1 | 470 Ω | SMD 0805 | bereits da | Entlade-Schutzwiderstand

Kondensatoren
C1,2,5 | 3 | 100 nF | SMD 0805 | bereits da | VCC-Abblockkondensatoren
C3 | 1 | 100 nF | SMD 0805 | bereits da | VCC-Abblockkondensator
C4 | 1 | 100 nF | SMD 0805 | bereits da | AVCC-Abblockkondensator
C6, C7 | 2 | 22 pF | THT Disc P2.50 | bereits da | Quarz-Lastkondensatoren
C8 | 1 | 10 nF | SMD 0805 | bereits da | Entpreller SW1

Stecker / Mechanik / Anzeige
Y1 | 1 | Crystal 16 MHz | HC-49/U Vertical | bereits da | Taktgenerator ATmega
J1 | 1 | USB Micro-B | Molex 47346-0001 | bereits da | Versorgungseingang
J2 | 1 | PinHeader 1×4 | Vertical | bereits da | OLED-Anschluss
J3 | 1 | Schraubklemme | Phoenix MKDS P5.08 2-pol. | bereits da | DUT-Anschluss
J4 | 1 | AVR-ISP-6 | PinHeader 2×3 P2.54 | bereits da | ISP-Programmierung
JTP1-10 | 10 | Testpunkte | PinHeader 1×1 P2.54 | bereits da | Inbetriebnahme-Testpunkte
SW1 | 1 | Taster 6×6 | SW_PUSH_6mm_H5mm | bereits da | Start-Taster
D1 | 1 | LED grün 5 mm | LED_D5.0mm THT | bereits da | LED_PWR
D2 | 1 | LED rot 5 mm | LED_D5.0mm THT | bereits da | LED_ERR
OLED | 1 | SSD1306 0,96" | I²C 4-Pin | bereits da | Messwertanzeige

KapTester V2 · BOM V2 · Nico Schmidt · IHK Osnabrück AP2 2026

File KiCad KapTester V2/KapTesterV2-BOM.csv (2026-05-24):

Reference | Qty | Value | DNP | Exclude from BOM | Exclude from Board | Footprint | Datasheet
C1,C2,C5 | 3 | 100nF |  |  |  | Capacitor_SMD:C_0805_2012Metric_Pad1.18x1.45mm_HandSolder | ~
C3 | 1 | 100nF, VCC |  |  |  | Capacitor_SMD:C_0805_2012Metric_Pad1.18x1.45mm_HandSolder | ~
C4 | 1 | 100nF, AVCC |  |  |  | Capacitor_SMD:C_0805_2012Metric_Pad1.18x1.45mm_HandSolder | ~
C6,C7 | 2 | 22pF |  |  |  | Capacitor_THT:C_Disc_D3.4mm_W2.1mm_P2.50mm | ~
C8 | 1 | 10nF |  |  |  | Capacitor_SMD:C_0805_2012Metric_Pad1.18x1.45mm_HandSolder | ~
D1 | 1 | LED_PWR |  |  |  | LED_THT:LED_D5.0mm | ~
D2 | 1 | LED_ERR |  |  |  | LED_THT:LED_D5.0mm | ~
J1 | 1 | USB_B_Micro |  |  |  | Connector_USB:USB_Micro-B_Molex_47346-0001 | ~
J2 | 1 | Conn_01x04 |  |  |  | Connector_PinHeader_2.54mm:PinHeader_1x04_P2.54mm_Vertical | ~
J3 | 1 | Conn_01x02 |  |  |  | TerminalBlock_Phoenix:TerminalBlock_Phoenix_MKDS-1,5-2-5.08_1x02_P5.08mm_Horizontal | ~
J4 | 1 | AVR-ISP-6 |  |  |  | Connector_PinHeader_2.54mm:PinHeader_2x03_P2.54mm_Vertical | ~
JTP1 | 1 | TP-USB5V |  |  |  | Connector_PinHeader_2.54mm:PinHeader_1x01_P2.54mm_Vertical | ~
JTP2 | 1 | TP-5VBOARD |  |  |  | Connector_PinHeader_2.54mm:PinHeader_1x01_P2.54mm_Vertical | ~
JTP3 | 1 | TP-SDA |  |  |  | Connector_PinHeader_2.54mm:PinHeader_1x01_P2.54mm_Vertical | ~
JTP4 | 1 | TP-LM317IN |  |  |  | Connector_PinHeader_2.54mm:PinHeader_1x01_P2.54mm_Vertical | ~
JTP5 | 1 | TP-GND |  |  |  | Connector_PinHeader_2.54mm:PinHeader_1x01_P2.54mm_Vertical | ~
JTP6 | 1 | TP-ADC |  |  |  | Connector_PinHeader_2.54mm:PinHeader_1x01_P2.54mm_Vertical | ~
JTP7 | 1 | TP-AVCC |  |  |  | Connector_PinHeader_2.54mm:PinHeader_1x01_P2.54mm_Vertical | ~
JTP8 | 1 | TP-RESET |  |  |  | Connector_PinHeader_2.54mm:PinHeader_1x01_P2.54mm_Vertical | ~
JTP9 | 1 | TP-MEAS |  |  |  | Connector_PinHeader_2.54mm:PinHeader_1x01_P2.54mm_Vertical | ~
JTP10 | 1 | TP-DISCH |  |  |  | Connector_PinHeader_2.54mm:PinHeader_1x01_P2.54mm_Vertical | ~
Q1 | 1 | IRLML6402 |  |  |  | Package_TO_SOT_SMD:SOT-23 | https://www.infineon.com/dgdl/irlml6402pbf.pdf?fileId=5546d462533600a401535668d5c2263c
Q2 | 1 | 2N7002 |  |  |  | Package_TO_SOT_SMD:SOT-23 | https://www.onsemi.com/pub/Collateral/NDS7002A-D.PDF
R1 | 1 | 1k Ω |  |  |  | Resistor_THT:R_Axial_DIN0207_L6.3mm_D2.5mm_P7.62mm_Horizontal | ~
R2,R3 | 2 | 100K Ω |  |  |  | Resistor_SMD:R_MELF_MMB-0207 | ~
R4,R5 | 2 | 4,7K Ω |  |  |  | Resistor_SMD:R_0805_2012Metric_Pad1.20x1.40mm_HandSolder | ~
R6,R7 | 2 | 330 Ω |  |  |  | Resistor_SMD:R_MELF_MMB-0207 | ~
R8 | 1 | 1,2K Ω |  |  |  | Resistor_THT:R_Axial_DIN0207_L6.3mm_D2.5mm_P7.62mm_Horizontal | ~
R9 | 1 | 100k Ω |  |  |  | Resistor_THT:R_Axial_DIN0207_L6.3mm_D2.5mm_P7.62mm_Horizontal | ~
R10 | 1 | 10K Ω |  |  |  | Resistor_THT:R_Axial_DIN0207_L6.3mm_D2.5mm_P7.62mm_Horizontal | ~
SW1 | 1 | SW_Push |  |  |  | Button_Switch_THT:SW_PUSH_6mm_H5mm | ~
U1 | 1 | ATmega328P-AU |  |  |  | Package_QFP:TQFP-32_7x7mm_P0.8mm | http://ww1.microchip.com/downloads/en/DeviceDoc/ATmega328_P%20AVR%20MCU%20with%20picoPower%20Technology%20Data%20Sheet%2040001984A.pdf
U2 | 1 | LM317L_SOT-89 |  |  |  | Package_TO_SOT_SMD:SOT-89-3 | http://www.ti.com/lit/ds/symlink/lm317l.pdf
Y1 | 1 | Crystal 16MHz |  |  |  | Crystal:Crystal_HC49-U_Vertical | ~

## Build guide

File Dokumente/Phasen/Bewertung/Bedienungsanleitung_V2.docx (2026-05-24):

Bedienungsanleitung

KapTester V2 │ Bewertung │ AP2 2026

⚠ Sicherheitshinweise

· Gerät nur mit 5 V DC / USB betreiben – kein Netzanschluss 230 V!

· Kondensatoren vor dem Anschließen entladen (Restspannung > 5 V kann die Schaltung beschädigen).

· Polung am DUT-Anschluss beachten: DUT+ (Plus) an Klemme mit +-Beschriftung.

· Gerät nicht auf leitfähigen Oberflächen betreiben (keine Abdeckung / kein Gehäuse in V2).

· Nicht für sicherheitsrelevante Messungen verwenden (Prototyp, ±20 % Toleranz).

1 Inbetriebnahme und Messablauf

Schritt | Aktion | Erwartetes Ergebnis
1 | USB-Kabel in J1 (USB Micro-B) einstecken (Laptop oder USB-Netzteil ≥ 500 mA). | Grüne LED (D1/LED_PWR) leuchtet. Betriebsbereitschaft.
2 | Kondensator auf Polarität prüfen. DUT+ (Pluspol) an Klemme J3-Pin1 (+), DUT– an J3-Pin2 (–). Schraubklemme mit Schraubenzieher festziehen. | Kondensator sicher und korrekt kontaktiert.
3 | START-Taster (SW1) drücken. | Messung startet. Grüne LED leuchtet konstant oder OLED zeigt Fortschritt.
4 | Warten bis Messung abgeschlossen (typ. < 5 s für 1.000 µF, ca. 10 s für 10.000 µF). | OLED zeigt Kapazitätswert in µF. Grüne LED = OK.
5 | Ergebnis ablesen. Toleranz ±20 % (Plausibilitätsprüfung, keine Kalibrierung). | Kapazität in µF auf OLED-Display.
6 | Warten bis Entladevorgang abgeschlossen (ca. 10 s nach Messung, OLED zeigt Entladestatus). | MEAS_NODE < 0,1 V. Gerät bereit für nächste Messung.
7 | Kondensator abklemmen und entnehmen. | Gerät ist messbereit für nächsten DUT.

2 Anzeigen und Fehlerbehebung

Anzeige | Bedeutung | Maßnahme
Grüne LED leuchtet | Betriebsbereit / Messung OK | Keine Maßnahme erforderlich.
Rote LED leuchtet | Fehler: Verpolung, Timeout oder kein DUT erkannt | DUT-Polung prüfen, Klemme festziehen, erneut START drücken.
OLED: Fehlermeldung | Timeout (kein plausibles Ergebnis in ≤ 15 s) | Kondensator prüfen (≥ 10 µF, korrekt angeschlossen), erneut messen.
Keine LED nach Einschalten | Kein Strom – USB nicht erkannt | USB-Kabel und -Stecker prüfen, anderen Port verwenden.
OLED dunkel, aber LED leuchtet | OLED nicht angeschlossen oder Firmware-Problem | J2-Stecker prüfen (4-polig, GND–VCC–SCL–SDA). Firmware prüfen.
Messung startet nicht (SW1 ohne Reaktion) | Firmware nicht geflasht oder Quarz-Problem | Firmware via J4/USBasp flashen (avrdude, Fuse Bits prüfen).
Messwert stark abweichend (> 50 %) | DUT beschädigt oder Referenzwert falsch | Mit bekanntem Referenzkondensator prüfen. Kalibrierung nicht möglich.

3 Technische Daten

Parameter | Wert
Messbereich | 10 µF – 10.000 µF
Messprinzip | Konstantstromladung (I = 1,042 mA, LM317L) + ADC-Zeitmessung (ATmega328P-AU)
Messgenauigkeit | ±20 % (Plausibilitätsprüfung, keine Kalibrierung mit Referenznormal)
ADC-Referenz | Intern 1,1 V (ATmega328P-AU)
Versorgung | 5 V DC, USB Micro-B (J1)
Stromaufnahme | ca. 20 – 50 mA (typisch)
Messzeit typisch | < 5 s (1.000 µF) · ca. 10 s (10.000 µF)
Entladezeit | ≤ 10 s (4.700 µF auf < 0,1 V, via Q2 + R20 = 470 Ω)
Verpolschutz | IRLML6402 PMOS (Q1), Gate-Teiler 1 MΩ / 100 kΩ (VGS ≈ −4,5 V)
DUT-Anschluss | Schraubklemme J3, 2-polig, Raster 5,08 mm
Platinengröße | 90 × 70 mm, 2-lagig, FR-4
Programmierung | USBasp via J4 (AVR-ISP-6), avrdude

4 Anschlüsse (Übersicht)

Ref. | Position | Funktion | Bemerkung
J1 | Kante links | USB Micro-B – Versorgungseingang 5 V DC | Molex 47346-0001
J2 | Kante oben | OLED-Header 4-polig (GND–VCC–SCL–SDA) | SSD1306 I²C, Adresse 0x3C
J3 | Kante rechts | DUT-Schraubklemme: Pin1 = DUT+ / Pin2 = DUT– | Polung auf Silkscreen beachten!
J4 | Innen | AVR-ISP-6 (2×3, P2.54) – Firmware-Programmierung | USBasp + 10→6-Pin-Adapter
SW1 | Vorderkante | START-Taster – Messung starten | Einmaliger Tastendruck
D1 (grün) | Vorderkante | LED_PWR – Betrieb OK / Messung erfolgreich | Vorwiderstand R7 = 330 Ω
D2 (rot) | Vorderkante | LED_ERR – Fehler / Timeout / Verpolung | Vorwiderstand R6 = 330 Ω
JTP1–10 | Verteilt | Testpunkte: USB5V, 5VBOARD, SDA, LM317IN, GND, ADC, AVCC, RESET, MEAS, DISCH | Inbetriebnahme / Service

KapTester V2 · Bedienungsanleitung V2 · BA-KapTester-V2 · Rev. 1.0 · Nico Schmidt · IHK Osnabrück AP2 2026

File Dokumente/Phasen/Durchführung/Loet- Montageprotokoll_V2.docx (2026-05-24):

Löt- und Montageprotokoll

KapTester V2 │ Durchführung │ AP2 2026

A) Identifikation / Rückverfolgbarkeit
Protokoll-ID | NicoSchmidt-AP2-KapTester-LMP-20260523-0002-R1.0
Datum | 23.05.2026
Projekt / Baugruppe | AP2 – Betrieblicher Auftrag 2026
Gerät / Objekt | Kapazitätstester V2 (Prototyp)
Seriennr. / Ident-Nr. | KapTester-V2-001
Revision PCB / Plan / FW | PCB V2.0 · Schaltplan V2.0 · FW3 (kaptesterfw3_v11.hex) (23.05.2026)
Schutzklasse | NA (Baugruppe ohne Gehäuse, SELV 5 V DC)
Bearbeiter / Prüfer | Nico Schmidt

B) Verfahren / Akzeptanzkriterien
Lötverfahren | [X] Handlöten THT [X] Handlöten SMD [] Nacharbeit [ ] NA
Montage | [X] Mechanische Montage (Stecker, Klemmen, Header) [ ] NA
Akzeptanzkriterien | [ ] IPC-A-610 Klasse 1 [X] Klasse 2 [ ] Klasse 3 [X] intern (Kurz-Check F)

C) Material
Lot (Legierung / ∅) | SN3.0AG0.5CU3.5%, 0,5 mm · Weller WSW SAC M1 / T0051388299
Flux | [X] No-Clean, NC-559-ASM
Charge / Datum | NA

D) Lötparameter / Prozess
Lötstation | Weller PU 81
Lötspitze | Meißelspitze (für SMD) / Standardspitze (für THT)
Temperatur | 375 °C
Kontaktzeit | [X] THT: 1–3 s [X] SMD: 0,5–2 s [ ] abweichend
Vorwärmung | [ ] Ja [X] Nein [ ] NA
Reinigung | [X] keine (No-Clean) [ ] IPA [ ] wässrig

Schritt | Gruppe / Bauteile | Datum / Kürzel | Bemerkung
1 | SMD Passivteile 0805 C1,C2,C3,C4,C5,C8 R4,R5 | 27.04.2026 | Pinzette, Lötpaste sparsam · Orientierung egal (kein Pol)
2 | SMD MELF-Widerstände R2,R3,R6,R7 | 27.04.2026 | Runde Bauteile – Pad-Mitte fixieren, dann zweite Seite
3 | SOT-23 SMD-ICs Q1 (IRLML6402), Q2 (2N7002) | 27.04.2026 | Pin 1 / Gate-Markierung beachten · Datenblatt prüfen
4 | SOT-89 LM317L U2 | 27.04.2026 | Großer mittlerer Pad (VO) zuerst heften
5 | TQFP-32 ATmega328P-AU U1 | 27.04.2026 | Pin 1 = Markierung Ecke oben links · Flux-Hilfe, Entlötlitze bereit · Lupe verwenden
6 | THT Widerstände R1,R8,R9,R10 | 27.04.2026 | Stehend/liegend gemäß Footprint · Drahtenden kürzen
7 | SMD Widerstand R20 (470 Ω, SMD 0805) | 27.04.2026 | R20 Entladeschutzwiderstand – V2-Neu
8 | Quarz + Lastkondensatoren Y1, C6, C7 | 27.04.2026 | Y1 stehend HC-49/U · C6/C7 je 22 pF direkt daneben
9 | USB Micro-B Buchse J1 (Molex 47346-0001) | 27.04.2026 | 4 THT-Anker zuerst · Mechanisch fest bevor löten
10 | PinHeader / ISP / OLED J2, J4, JTP1–JTP10 | 27.04.2026 | J4: 2×3, Pin 1 markieren · JTP: je 1-polig
11 | DUT-Schraubklemme J3 (Phoenix P5.08) | 27.04.2026 | Gerade ausrichten, festschrauben, dann löten
12 | LEDs + Taster D1 (grün), D2 (rot), SW1 | 27.04.2026 | D1/D2: Kathode (kürzeres Bein) = Markierungsring · SW1: kein Pol

E) Gesamtergebnis Sichtprüfung
Sichtprüfung | [x] Bestanden [ ] Nicht bestanden
Abweichung / Nacharbeit | [x] Nein [ ] Ja → Abschnitt G ausfüllen
Bemerkung | --

Nr. | Kriterium | Referenz | OK? | Bemerkung
1 | Benetzung vollständig (Pad + Anschluss) | IPC-A-610 Kl.2 | Ok | Sauber
2 | Keine Lötbrücken / Shorts (visuell, Lupe) | Alle Pads | Ok | Sauber
3 | Keine kalten Lötstellen (matt/kristallin) | Alle Pins | Ok | Sauber
4 | Keine PCB-/Pad-Schäden (Delamination/Pad lift) | Alle Pads | Ok | Keine Schäden
5 | THT-Drahtenden korrekt gekürzt (kurz, ohne Grat) | R1,R8,R9,R10,Y1,C6,C7 | Ok | Korrekt & sauber
6 | SMD-Ausrichtung korrekt (kein Tombstoning/Schiefstand) | 0805, MELF, SOT | Ok | Korrekt
7 | Polung / Orientierung korrekt geprüft | D1(Kathode), D2(Kathode), U1(Pin1), U2(Tab), Q1(Gate=Pin1), Q2(Gate=Pin1), J3(DUT+/DUT−) | Ok | Korrekt
8 | R20 (470 Ω) in Serie mit Q2-Drain vorhanden (V2-neu) | Schaltplan V2, R20 | Ok | Korrekt
9 | Flux-Rückstände akzeptabel / Reinigung | No-Clean | Ok | Sauber
10 | Mechanische Montage fest (J3 Klemme gerade+fest, J1 USB verankert) | J1, J3 | Ok | Fest & gerade
11 | Keine Fremdkörper / Späne, Arbeitsbereich sauber | Platine gesamt | Ok | sauber

G) Abweichungen / Nacharbeit
Ref./Ort | Abweichung / Fehlerbild | Maßnahme | Referenz | Nachprüfung i.O.

H) Compliance / Hinweise
ESD | Alle ESD-Schutzmaßnahmen gemäß IEC 61340-5-1 angewendet (ESD-Matte, Armband, antistatische Ablage).
Werkzeuge | Verwendete Werkzeuge waren funktionsfähig und geeignet (Lötstation kalibriert, Spitze in gutem Zustand).

I) Freigabe
Rolle | Name | Datum | Unterschrift
Bearbeiter | Nico Schmidt | 27.04.2026
Prüfer | – | – | –

KapTester V2 · Löt- und Montageprotokoll V2 · Nico Schmidt · IHK Osnabrück AP2 2026

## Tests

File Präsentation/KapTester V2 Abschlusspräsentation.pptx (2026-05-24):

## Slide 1

IHK OSNABRÜCK · AP2 2026

KapTester V2

Kapazitätstester für Elektrolytkondensatoren
(10 µF – 10.000 µF)

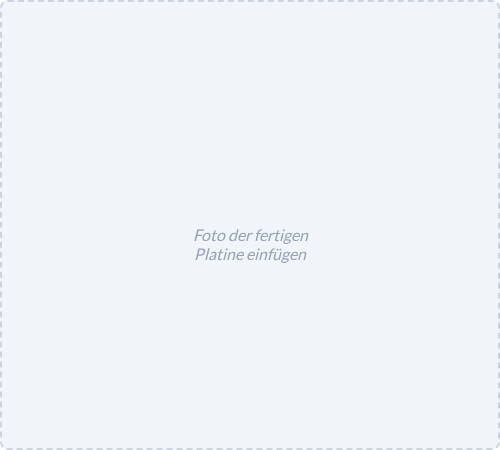
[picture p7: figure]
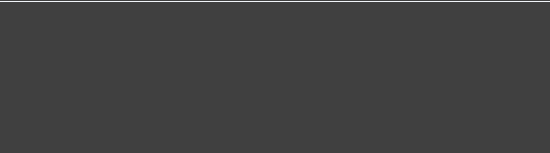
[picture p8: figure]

Nico Schmidt
Elektroniker für Geräte und Systeme

GBS TEMPEST und Service GmbH

KapTester V2 · Nico Schmidt · Prüflingsnr: (133)-1251

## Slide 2

Projekt-Gliederung

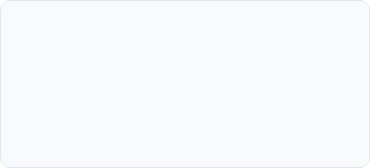
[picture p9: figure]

Problem & Zielsetzung

01 Auftrag

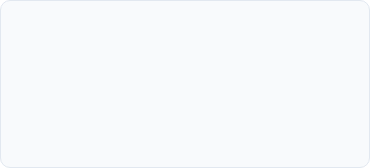
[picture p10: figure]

Physik & Grundlagen

02 Messprinzip

System & Architektur

03 Schaltung

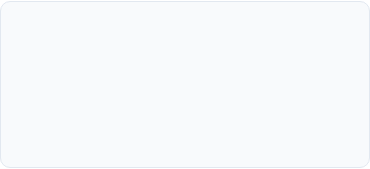
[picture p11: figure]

Analyse Risiko R6

04 V1 - Fehler

Fixes & Korrekturen

05 V2 - Lösung

Löten & Montage

06 Fertigung

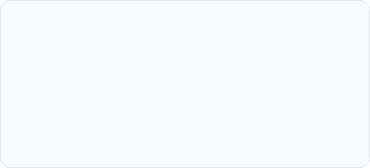
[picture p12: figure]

Software-Design C

07 Firmware

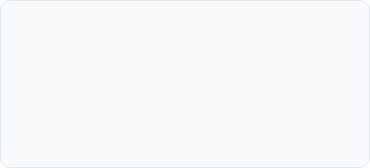
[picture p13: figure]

Messung & JTPs

08 Validierung

Learnings & Ausblick

09 Fazit

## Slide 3

Ausgangssituation & Auftrag

✓ Vergleich UNI-T UT61E (> 30s) zu KapTester (< 15s) für 10 mF.

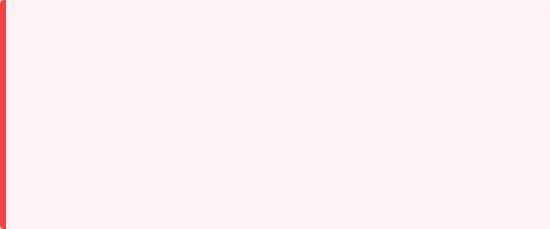
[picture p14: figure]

Das Problem

Kein Prüfmittel für große Elkos (> 1 mF) im Betrieb.

DMM ungenau, zu langsam (> 30s) oder fehlerhaft.

Sicherheitsrisiko durch Restladung/Verpolung.

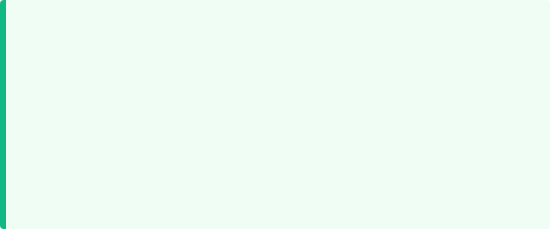
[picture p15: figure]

Das Ziel

Messbereich: 10 µF – 10.000 µF.

PMOS Verpolschutz: Sicherheit für MCU & DUT.

Autom. Entladung: ≤ 10s via NMOS Q2.

Benutzerführung: OLED Interface.

•

•

•

•

•

•

•

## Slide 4

Idee & Messprinzip

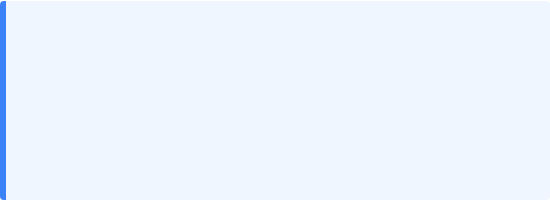
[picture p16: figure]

Technische Umsetzung

I = 1,042 mA: Konstantstrom via LM317L.

ΔU = 1,1 V: Interne Bandgap-Referenz.

t = Ladezeit: Hardware-Timer Messung.

C ist direkt proportional zur Ladezeit t.

Begründung ±20% Toleranz:
Interne Ref (10%) + Widerstände (1%) + Bauteilstreuung. Konservativ gewählt für höchste Plausibilität.

•

•

•

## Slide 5

Schaltungsentwurf & System


Schutz & Power

IRLML6402 (PMOS) Verpolschutz; USB 5V mit Abblockkondensatoren.

Messpfad

LM317L Stromquelle; NMOS Entladepfad mit 470 Ω Strombegrenzung.

Rechenkern

ATmega328P-AU (TQFP-32); SSD1306 OLED via I2C; 16 Testpunkte.

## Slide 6

V1 – Kritischer Planungsfehler


Analyse (Risiko R6)

Symbol ≠ Footprint ≠ Datenblatt

KiCad-Symbol DIP-28 genutzt, aber TQFP-32 bestellt. Alle 32 Pins falsch verdrahtet. Platine V1 nie funktional.

Lektion: Datenblatt-Validierung VOR Bestellung.

R20 fehlte in V1 (Entlade-Risiko).


•

•

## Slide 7

V2 – Systematische Korrektur

✓ DRC = 0 Fehler · Optimierte Masseflächen (Groundplane)


MCU FIX

Korrektes TQFP-32 Footprint & Symbol. Komplette Neu-Konstruktion des Routings.

SICHERHEIT

R20 (470 Ω) integriert. Schützt NMOS Q2 vor Entlade-Stromspitzen.

GATE-BIAS

Optimierung PMOS Gate-Teiler auf 1M/100k für stabiles VGS (-4,5V).

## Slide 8

Durchführung & Bestückung


Fertigungs-Fakten

IPC-A-610 Klasse 2: Industrieller Standard für Bestückungsqualität.

SMD-Technik: Handlötung bei 375 °C; Fokus auf 0,8 mm Pin-Pitch des TQFP-32.

Reihenfolge: Passiv (0805) → ICs → THT-Komponenten.

QC: Sichtprüfung unter Lupe/Mikroskop auf Brücken & Kaltlötstellen.

•

•

•

•

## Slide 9

Firmware-Highlights (v3.5)

Kino-Timing: Flackerfreie UI-Animation, dynamisch angepasst an die Ladekurve (220 ms - 450 ms) für authentisches Benutzerfeedback.

2-AUS-3 PLAUSIBILITÄTSFILTER


uint32_t

uint32_t

PRÄZISES HARDWARE-POLLING


// Filtert Ausreißer (±15%)

if

return

do

if

break

if

return

return

// FAIL bei Streuung

// CPU Fokus auf Zeitmessung

while

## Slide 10

Messprotokoll & Validierung

DUT (Nennwert) | Toleranz ±20% | Referenz (DMM) | KapTester V2
100 µF | 80 – 120 µF | 104,2 µF | [Daten] µF
1.000 µF | 800 – 1.200 µF | 985,0 µF | [Daten] µF
4.700 µF | 3.760 – 5.640 µF | 4.620,0 µF | [Daten] µF
10.000 µF | 8.000 – 12.000 µF | 9.450,0 µF | [Daten] µF

Testpunkte (JTP): USB: 5,05V; LM317: 4,45V; ADC: 1,1V linear.

Validierung: Deterministische Messung & automatischer Entladepfad erfolgreich.

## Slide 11

Fazit & Selbstreflexion


Learnings

KiCad: Routing & Footprint-Validierung.

SMD: Handhabung TQFP-32 & 0805.

Embedded: ATmega Timer, ISR & ADC.

Coding: C-Systemdesign (Modularität).


Reflexion

Prototyping: V1→V2 Iteration lehrreich.

Qualität: Firmware-Filterung steigert Hardware-Präzision massiv.

Ausblick: Gehäusebau (3D-Druck) & ESR-Messung als V3 Erweiterung.

•

•

•

•

•

•

•

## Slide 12

Vielen Dank!

Haben Sie noch Fragen zum KapTester V2?

Nico Schmidt

GBS TEMPEST und Service GmbH

IHK Osnabrück · AP2 2026

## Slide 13

Technisches Datenblatt (Summary)

* Diese Folie dient als Referenz während der Fachdiskussion.


Elektrische Parameter

• Versorgung: 5V USB (+/- 5%)
• Ladestrom: 1,042 mA (LM317L)
• Ref-Spannung: 1,1 V (intern)


Mess-Spezifikation

• Bereich: 10 µF – 10.000 µF
• Toleranz: ±20% (bewusst konservativ)
• Auflösung: 16 µs pro Timer-Tick

Hardware-Komponenten

• MCU: ATmega328P (16 MHz Quarz)
• Schutz: PMOS IRLML6402
• Entladung: 2N7002 + 470 Ω

Software-Features

• 2-aus-3 Plausibilitätsfilter
• HW-Polling für Zeitpräzision
• Dynamisches Kino-Timing (UI)

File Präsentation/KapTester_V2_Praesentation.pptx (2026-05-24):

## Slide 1

IHK Osnabrück AP2 2026

KapTester V2

Entwicklung und Aufbau eines Kapazitätstesters
für Elektrolytkondensatoren (10 µF – 10.000 µF)

Beruf: Elektroniker für Geräte und Systeme
Name: Nico Schmidt
Prüflingsnr.: (133)-1251
Betrieb: GBS TEMPEST und Service GmbH, Diepholz
Ausbilder: Andreas Moosmann


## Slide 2

Gliederung

Ausgangssituation & Auftrag

01

Bestückung – Löten & Montage nach IPC-A-610

06

Idee & Messprinzip

Programmierung & Firmware

02

07

Konkretisierung: Schaltung & Blockschaltbild

03

Inbetriebnahme & Messergebnisse

08

V1-Platine – Aufbau & kritischer Fehler

04

Fazit & Selbstreflexion

09

V2-Platine – Analyse, Korrektur & Finalisierung

05

KapTester V2 · Nico Schmidt · IHK Osnabrück AP2 2026

2

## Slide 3

01 Auftrag

Ausgangssituation & Auftrag

Warum dieses Projekt?

⚠ Das Problem

- Kein dediziertes Prüfmittel
für Elektrolytkondensatoren (> 1.000 µF) im Betrieb.
- Handelsübliche Multimeter
ungenau, zu langsam oder kein Messbereich > 9.999 µF.
- Sicherheitsrisiko
durch Restladung & Verpolung (bis 10.000 µF).

✓ Das Ziel

10 µF – 10.000 µF (Nachweis: Messprotokoll)

PMOS Q1 – kein Schaden bei Verpolung

Automatisch ≤ 10 s nach Messung

OLED (µF-Wert) + LED grün/rot

5 V USB · Abblockkond. C1–C5 an MCU

Messbereich:

Verpolschutz:

Entladepfad:

Anzeige:

Versorgung:

📊 DMM-Vergleich

UNI-T UT61E: max. 9.999 µF, ±3%+5 Dgt.

Ladezeit 10.000 µF: > 30 s, unreproduzierbar

KapTester: bis 10.000 µF, deterministisch, ≤ 15 s

±20% Toleranz – Begründung

Interne 1,1-V-Ref: ±10 % lt. ATmega-Datenblatt

R8 (1,2 kΩ): ±1 % → I-Abweichung < 1 %

Gesamt: ±20 % bewusst konservativ gewählt

Fertigung:

Eigene Leiterplatte, PCBWay, 2 Lagen

🔒 Kein Restladungs-Risiko

Q2 (NMOS) + R20 (470 Ω): automatischer Entladepfad

Firmware: Entladen nach JEDER Messung

Nachweis: 4.700 µF < 0,1 V in ≤ 10 s (Messprotokoll)

KapTester V2 · Nico Schmidt · IHK Osnabrück AP2 2026

3

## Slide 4

02 Messprinzip

Idee & Messprinzip

Wie misst man eine Kapazität zuverlässig?

C = I × t / U

C = I × t / U

Konstantstrom

1,042 mA

LM317L hält 1,25 V über R8 (1,2 kΩ)
I = 1,25 V / 1.200 Ω = 1,042 mA

Warum dieser Wert? Klein genug (kein Schaden), groß genug (10.000 µF in < 12 s)

I

Ladezeit

gemessen

ATmega 16-Bit Timer @ 16 MHz
Auflösung: 62,5 ns

Warum Timer? Messbar von ~10 ms (100 µF) bis 10,6 s (10.000 µF)

t

Schwellwert

1,1 V

Interne Referenz ATmega328P
(ADMUX: REFS1=1, REFS0=1)

Warum intern? Unabhängig von AVCC/USB-Schwankungen – stabiler Messpunkt

U

Toleranz ±20 %: ±10 % (interne 1,1-V-Ref lt. Datenblatt) + ±1 % (R8) + Bauteilstreuung → bewusst konservativ | mögliche Probleme: Erwärmung R8, Kabelwiderstand bei großen Elkos

KapTester V2 · Nico Schmidt · IHK Osnabrück AP2 2026

4

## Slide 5

03 Schaltung

Konkretisierung

Schaltungsentwurf & Systemarchitektur

KapTester V2 · Nico Schmidt · IHK Osnabrück AP2 2026


Design-Entscheidungen

🔌 Verpolschutz

PMOS IRLML6402
Gate-Teiler R2/R3

⚡ Konstantstrom

LM317L (SOT-89)
I = 1,042 mA

🔁 Entladepfad

NMOS 2N7002 + R20
470 Ω Strombegrenzer

💻 Mikrocontroller

ATmega328P-AU
TQFP-32, 16 MHz

📺 Anzeige

SSD1306 OLED + 2 LEDs
I²C 0x3C

5

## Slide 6

04 V1 – Fehler

V1 – Aufbau & kritischer Fehler

Was ist passiert?


❌ Kritischer Planungsfehler (Risikoanalyse R6)

KiCad-Symbol ATmega: DIP-28 (Simulation) statt TQFP-32 (Real-Bauteil)
→ Alle 32 Pins falsch verdrahtet → Platine V1 nie funktional

Was lief schief

- Symbol ≠ Footprint ≠ Datenblatt
- Pinbelegung nicht gegen Datenblatt geprüft
- Bestellung ohne ausreichende Verifikation

Weitere V1-Mängel

- R20 fehlte: kein Entlade-Schutzwiderstand
- PMOS Gate-Teiler: VGS nur −2,5 V statt −4,5 V
→ unsicheres Einschalten

KapTester V2 · Nico Schmidt · IHK Osnabrück AP2 2026

6

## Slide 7

05 V2 – Lösung

V2 – Analyse, Korrektur & Finalisierung

Vollständige Neugestaltung

ATmega Symbol korrigiert

Vorher: DIP-28 Simulationssymbol (falsch)

Nachher: ATmega328P-AU TQFP-32 (32 Pins, korrekt)

→ Kompletter Schaltplan & PCB neu aufgebaut

FIX 1


R20 = 470 Ω neu eingefügt

Vorher: Kein Schutzwiderstand an Q2-Drain

Nachher: 470 Ω in Serie → Einschaltstrom begrenzt

→ Schützt Q2 bei großen Elkos (10.000 µF)

FIX 2

PMOS Gate-Teiler optimiert

Vorher: 100 kΩ / 100 kΩ → VGS = −2,5 V

Nachher: 1 MΩ / 100 kΩ → VGS = −4,5 V

→ Robusteres, zuverlässiges Einschalten

FIX 3

✓ V2-PCB: DRC = 0 Fehler · 90×70 mm · 2-lagig · bei PCBWay bestellt

KapTester V2 · Nico Schmidt · IHK Osnabrück AP2 2026

7

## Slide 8

06 Durchführung

Durchführung – Bestückung & Aufbau

Löten nach IPC-A-610 Klasse 2


Bestückungsreihenfolge

1. SMD-Passivteile (0805, MELF)

2. SMD-ICs: SOT-23, SOT-89

3. ATmega328P-AU (TQFP-32)
Pinabstand 0,8 mm – Lupe!

4. THT-Bauteile & Stecker

5. Sichtprüfung: Brücken, Kaltlötstellen

'Kalt' = kalte Lötstelle: unzureichende Temperatur → matte, körnige Oberfläche, schlechte Benetzung, instabile Verbindung

IPC-A-610 Kl. 2 = 'Dedicated Service' · zuverlässige Industrieelektronik · 375 °C · No-Clean-Lot

KapTester V2 · Nico Schmidt · IHK Osnabrück AP2 2026

8

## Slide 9

07 Firmware

Programmierung & Firmware

ATmega328P-AU – avrdude / USBasp

Warum so?

→ Benutzersicherheit – keine Automessung

→ Schutz: Abbruch vor Ladeimpuls

→ LM317 liefert konstantes I

→ Simultan zum Laden → exaktes t

→ Interne Ref. – stabil, AVCC-unabhängig

→ Direkte Formel, kein Lookup nötig

→ Sofortige visuelle Rückmeldung

→ Sicherheit: < 0,1 V vor Entnahme

KapTester V2 · Nico Schmidt · IHK Osnabrück AP2 2026

Messablauf

Fuse Bits setzen (einmalig):

1

Warten auf SW1

avrdude -c usbasp -p m328p \
-U lfuse:w:0xFF:m \
-U hfuse:w:0xD9:m

2

Verpolprüfung

Firmware flashen:

avrdude -c usbasp -p m328p \
-U flash:w:kaptesterfw3_v11.hex:i

3

4

Kondensator laden

Timer starten

// Snippet 1: Messung + Berechnung
timer1_start();
do { adc_val = adc_read(); }
while (adc_val < ADC_THRESH);
ticks = timer1_stop();
// C = I x t / dU [in nF]
return (I_UA * TICK_US * ticks) / u_delta_mv;

5

ADC pollen ≥ 1,1 V

6

C = I × t / U berechnen

7

OLED + LED anzeigen

// Snippet 2: Plausibilitaetsfilter +-15%
((hi-lo)*100UL) <= (PLAUS_PCT * lo)
// 3 Werte -> bestes Ergebnis
p01&&p02&&p12 → Mittelwert(v0,v1,v2)
nur p01 → Mittelwert(v0,v1)
kein Match → FAIL (streuen zu stark)

8

Kondensator entladen

9

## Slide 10

08 IBN & Messung

Inbetriebnahme & Messergebnisse

Testpunkte JTP1–10 · 5 Referenz-Kondensatoren

Inbetriebnahme-Schritte

① Kurzschlusscheck GND↔+5V

② Ersteinschalten: 5V / 100 mA

③ Fuse Bits setzen (einmalig)

④ Firmware flashen (.hex)

⑤ Funktionstest: SW1 drücken

Testpunkte – Sollwerte

Messprotokoll – Referenzkondensatoren

DUT (Nennwert) | Toleranz ±20% | Messwert | OK?
100 µF | 80 – 120 µF | — µF | ⏳
1.000 µF | 800 – 1.200 µF | — µF | ⏳
4.700 µF | 3.760 – 5.640 µF | — µF | ⏳
10.000 µF | 8.000 – 12.000 µF | — µF | ⏳
Verpoltest | Fehleranzeige, kein Schaden | — | ⏳

JTP1

USB_5V

4,8–5,2 V

JTP2

JTP4

+5V_BOARD

LM317_OUT

≈ JTP1 ±50 mV

≈ 4,5 V

JTP6

JTP10

ADC_MEAS

DISCH_GATE

0 → 1,1 V linear

LOW / HIGH (Entl.)

⏳ Platzhalter – Messwerte nach V2-Inbetriebnahme eintragen

KapTester V2 · Nico Schmidt · IHK Osnabrück AP2 2026

10

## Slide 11

09 Fazit

Fazit & Selbstreflexion

Was habe ich gelernt?

✓ Was gut lief

- Vollständige KiCad-Toolchain (Schaltplan → PCB → Gerber)
- SMD-Löten mit Flux – zugänglicher als erwartet
- Fehler früh erkannt und systematisch analysiert (Risikoanalyse)

✗ Größter Fehler

- Symbol ≠ Footprint ≠ Datenblatt
→ V1 komplett nicht funktional
- Lektion: Immer Datenblatt vor Bestellung prüfen

→ Was würde ich anders machen?

- Steckbrett-Test vor PCB-Design
- Footprint + Symbol IMMER sofort mit Datenblatt abgleichen
- Mehr Puffer bei Hardware-Projekten einplanen

KapTester V2 · Nico Schmidt · IHK Osnabrück AP2 2026

💡 Verbesserungspotenzial

- Gehäuse (3D-Druck) → alltagstauglicher
- Kalibrierung → von ±20% auf ±5%
- ESR-Messung als nächste Erweiterung

11

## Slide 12

Vielen Dank!

Ich stehe für Fragen zur Verfügung.

∿

Messprinzip

C = I · t / U

⬡

Hardware

ATmega + LM317 + PMOS

✕

Fehler → Fix

Footprint-Fail: DIP-28→TQFP-32 + R20 + Gate-Teiler

✓

Ergebnis V2

Idee → KiCad → Platine + Bauteile → FW1 (Simple) · FW2 (Testware) · FW3 (Ausgereift) → Abnahme

Nico Schmidt · (133)-1251 · GBS TEMPEST und Service GmbH · IHK Osnabrück AP2 2026

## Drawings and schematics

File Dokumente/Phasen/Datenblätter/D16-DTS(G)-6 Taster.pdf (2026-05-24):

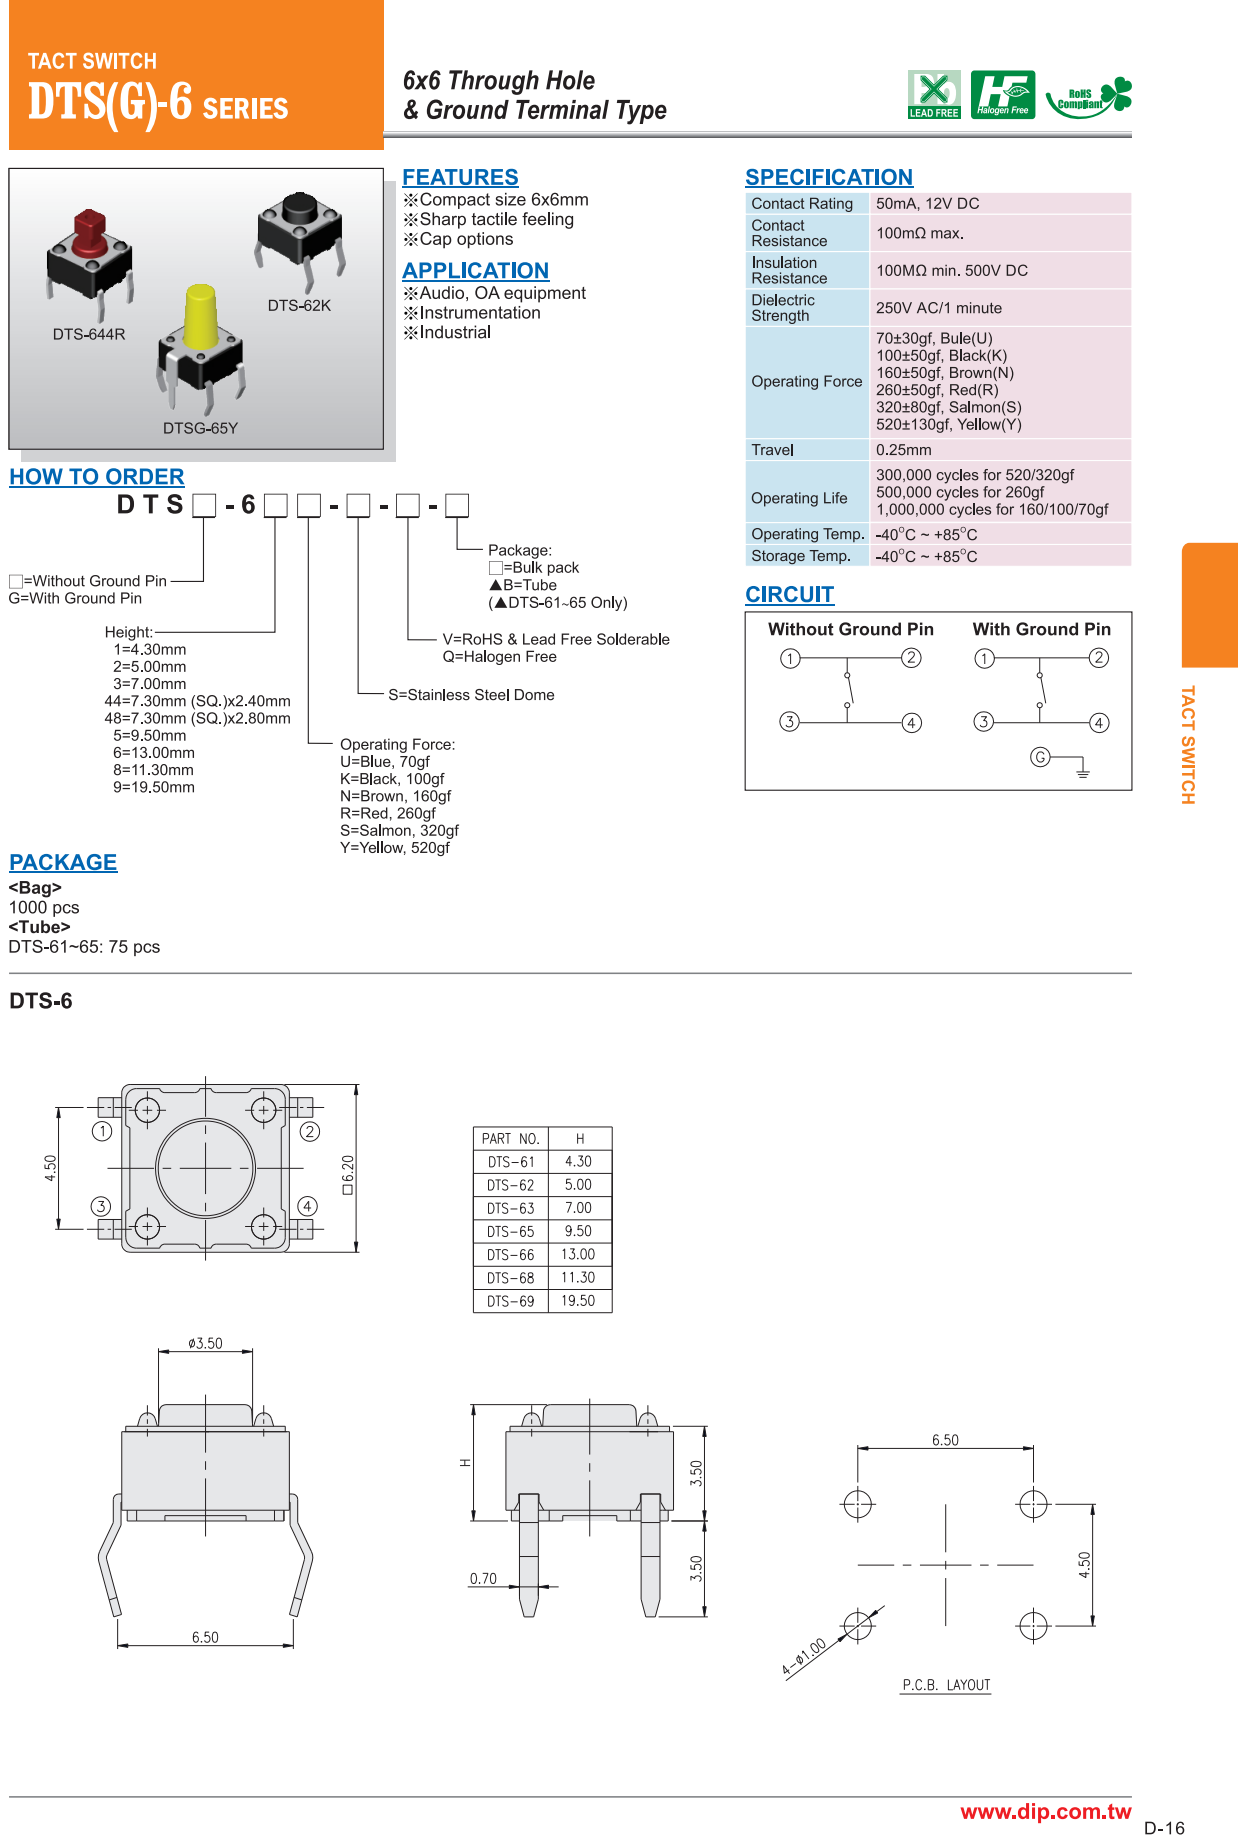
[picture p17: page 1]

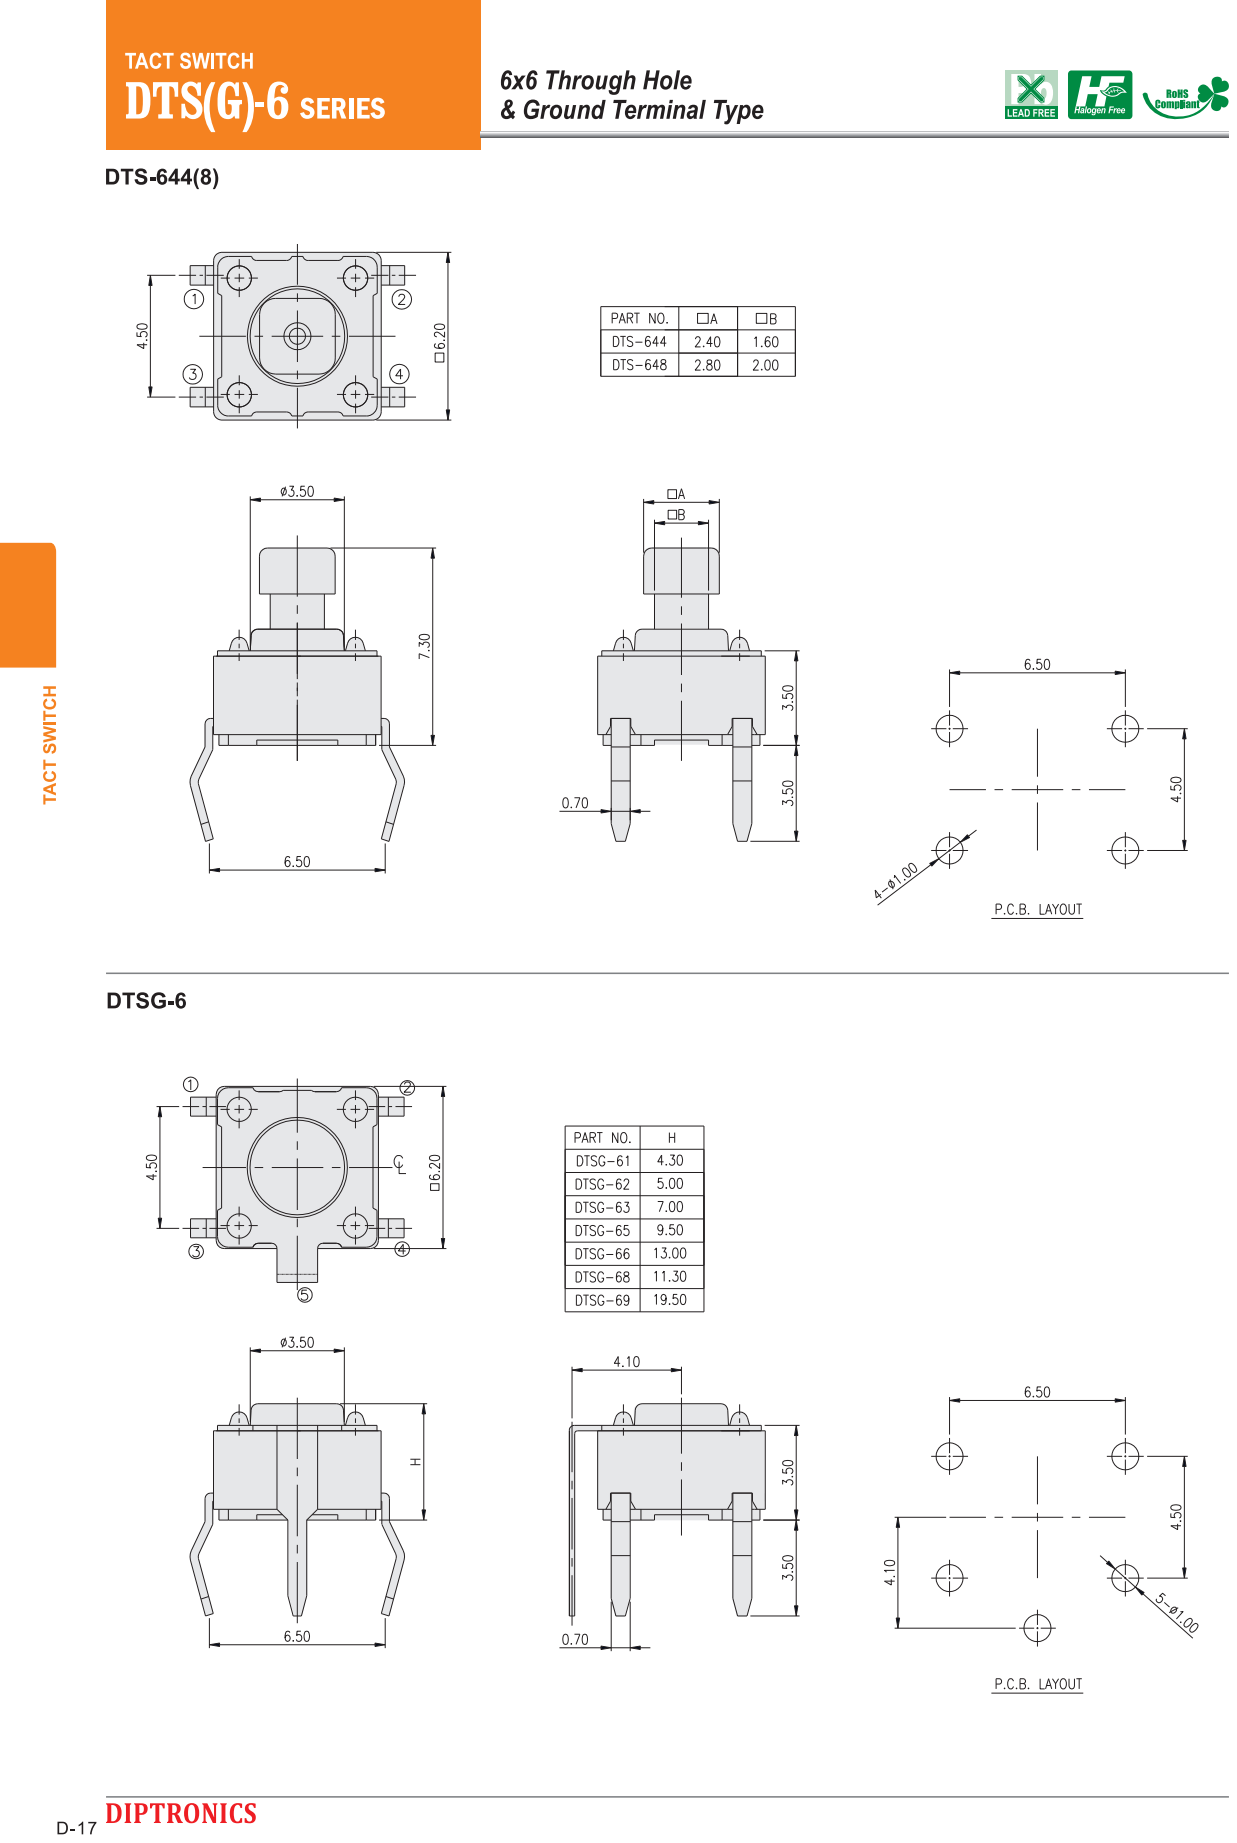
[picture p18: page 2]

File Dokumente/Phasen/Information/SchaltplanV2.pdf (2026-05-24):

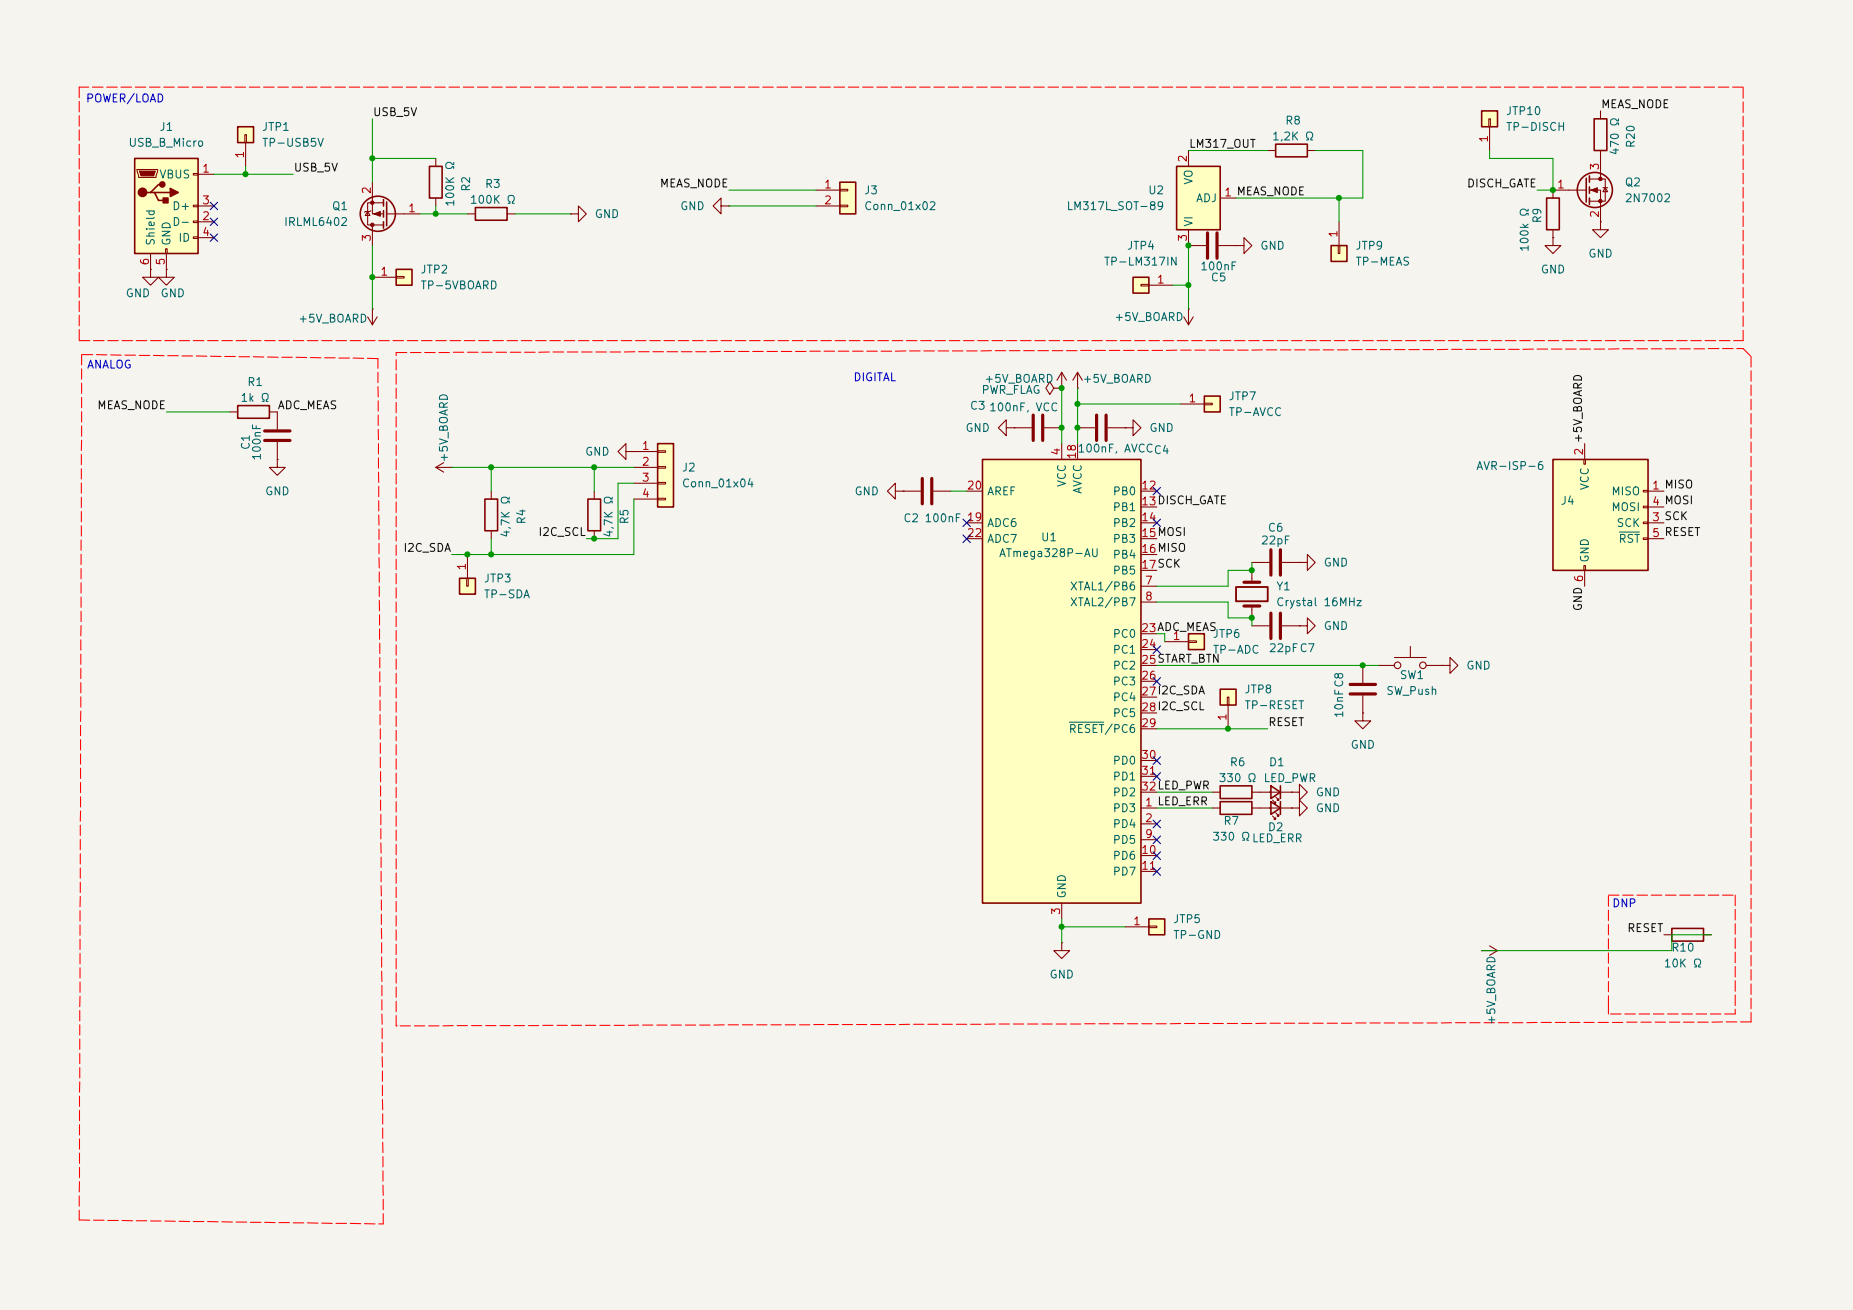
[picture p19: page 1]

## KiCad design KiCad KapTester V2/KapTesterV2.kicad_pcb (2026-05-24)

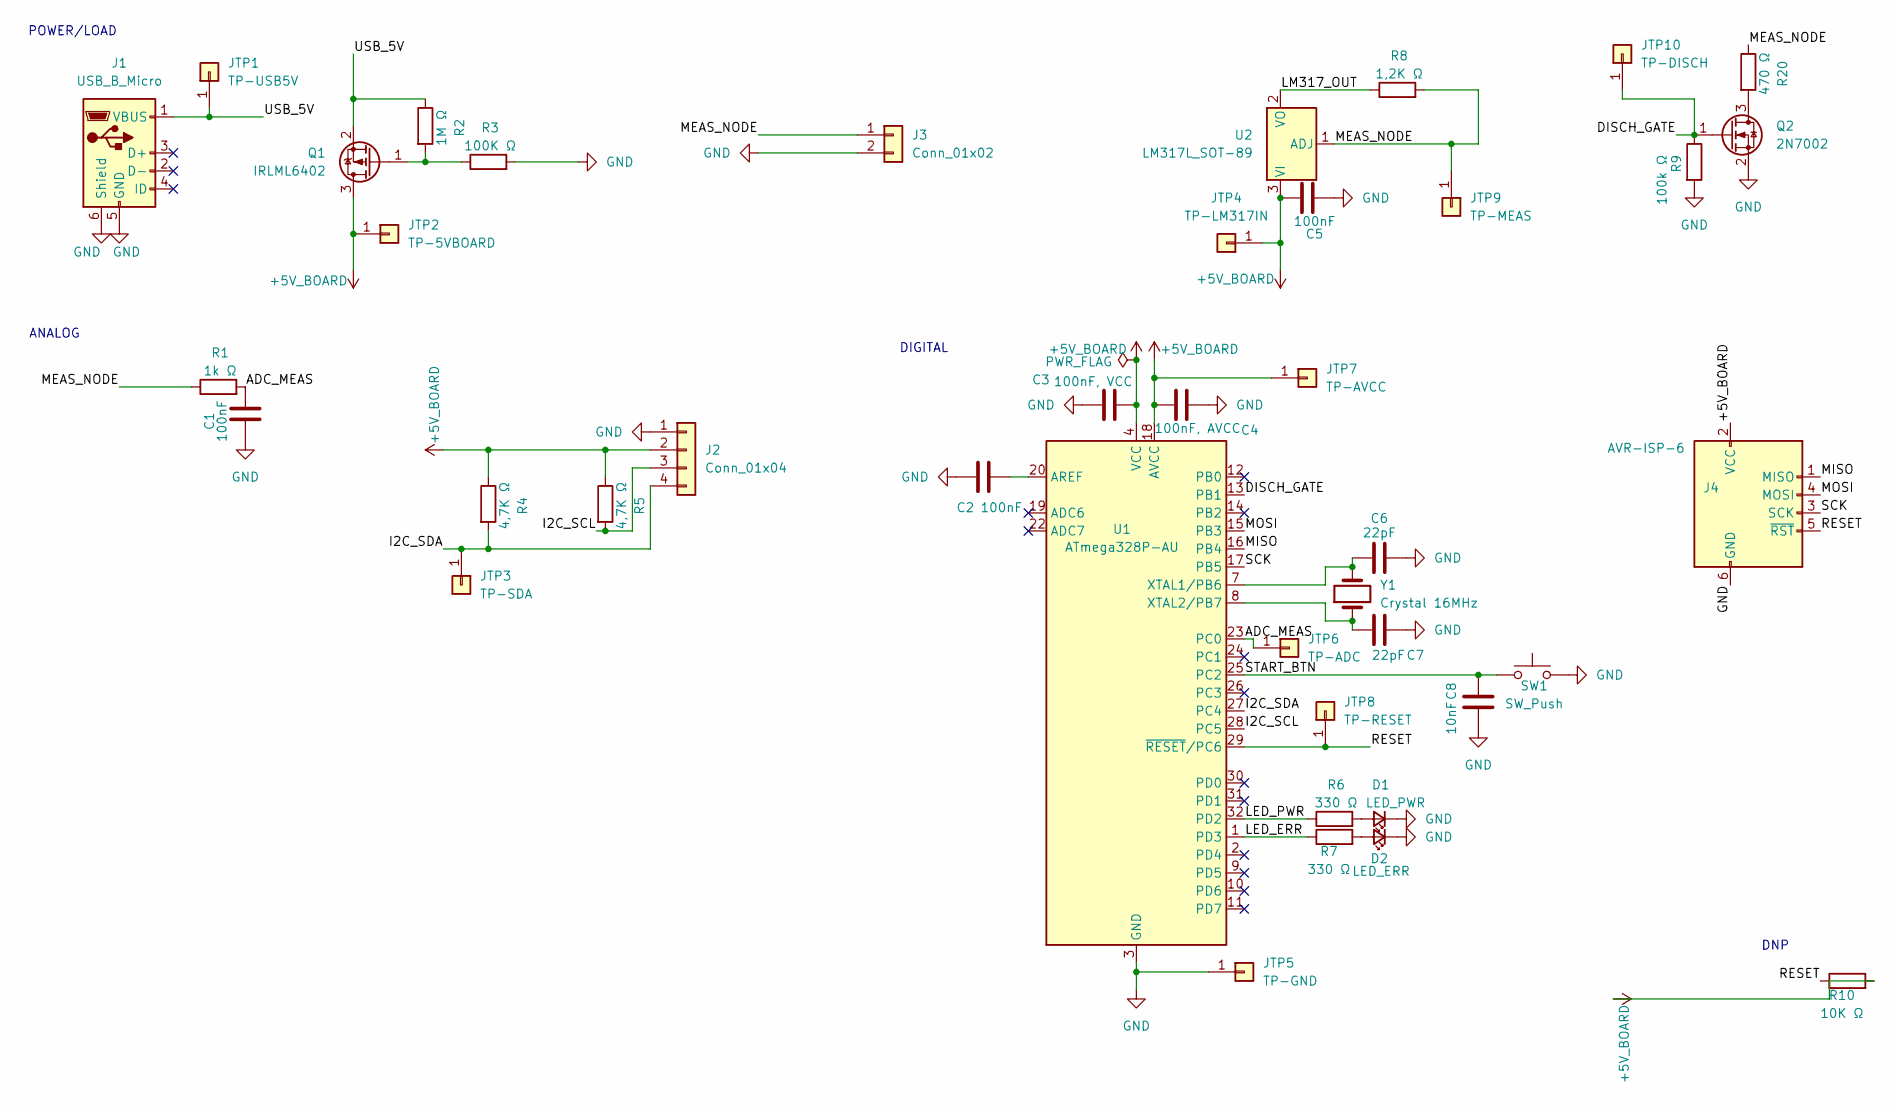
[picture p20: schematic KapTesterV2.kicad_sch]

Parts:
C1, C2, C5: 100nF; C_0805_2012Metric_Pad1.18x1.45mm_HandSolder
C3: 100nF, VCC; C_0805_2012Metric_Pad1.18x1.45mm_HandSolder
C4: 100nF, AVCC; C_0805_2012Metric_Pad1.18x1.45mm_HandSolder
C6, C7: 22pF; C_Disc_D3.4mm_W2.1mm_P2.50mm
C8: 10nF; C_0805_2012Metric_Pad1.18x1.45mm_HandSolder
D1: LED_PWR; LED_D5.0mm
D2: LED_ERR; LED_D5.0mm
J1: USB_B_Micro; USB_Micro-B_Molex_47346-0001
J2: Conn_01x04; PinHeader_1x04_P2.54mm_Vertical
J3: Conn_01x02; TerminalBlock_Phoenix_MKDS-1,5-2-5.08_1x02_P5.08mm_Horizont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
J4: AVR-ISP-6; PinHeader_2x03_P2.54mm_Vertical
JTP1: TP-USB5V; PinHeader_1x01_P2.54mm_Vertical
JTP2: TP-5VBOARD; PinHeader_1x01_P2.54mm_Vertical
JTP3: TP-SDA; PinHeader_1x01_P2.54mm_Vertical
JTP4: TP-LM317IN; PinHeader_1x01_P2.54mm_Vertical
JTP5: TP-GND; PinHeader_1x01_P2.54mm_Vertical
JTP6: TP-ADC; PinHeader_1x01_P2.54mm_Vertical
JTP7: TP-AVCC; PinHeader_1x01_P2.54mm_Vertical
JTP8: TP-RESET; PinHeader_1x01_P2.54mm_Vertical
JTP9: TP-MEAS; PinHeader_1x01_P2.54mm_Vertical
JTP10: TP-DISCH; PinHeader_1x01_P2.54mm_Vertical
Q1: IRLML6402; SOT-23
Q2: 2N7002; SOT-23
R1: 1k Ω; R_0805_2012Metric_Pad1.20x1.40mm_HandSolder
R2: 1M Ω; R_MELF_MMB-0207
R3: 100K Ω; R_MELF_MMB-0207
R4, R5: 4,7K Ω; R_0805_2012Metric_Pad1.20x1.40mm_HandSolder
R6, R7: 330 Ω; R_MELF_MMB-0207
R8: 1,2K Ω; R_Axial_DIN0207_L6.3mm_D2.5mm_P7.62mm_Horizontal
R9: 100k Ω; R_Axial_DIN0207_L6.3mm_D2.5mm_P7.62mm_Horizontal
R10: 10K Ω; R_Axial_DIN0207_L6.3mm_D2.5mm_P7.62mm_Horizontal
R20: 470 Ω; R_0805_2012Metric_Pad1.20x1.40mm_HandSolder
SW1: SW_Push; SW_PUSH_6mm_H5mm
U1: ATmega328P-AU; TQFP-32_7x7mm_P0.8mm
U2: LM317L_SOT-89; SOT-89-3
Y1: Crystal 16MHz; Crystal_HC49-U_Vertical

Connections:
+5V_BOARD: C3.2, C4.2, C5.2, J2.2, J4.2 (VCC), JTP2.1, JTP4.1, JTP7.1, Q1.3 (D), R4.1, R5.1, R10.2, U1.4 (VCC), U1.6 (VCC), U1.18 (AVCC), U2.3 (VI)
/ADC_MEAS: C1.2, JTP6.1, R1.2, U1.23 (PC0)
/DISCH_GATE: JTP10.1, Q2.1 (G), R9.1, U1.13 (PB1)
/I2C_SCL: J2.3, R5.2, U1.28 (PC5)
/I2C_SDA: J2.4, JTP3.1, R4.2, U1.27 (PC4)
/LED_ERR: R7.1, U1.1 (PD3)
/LED_PWR: R6.1, U1.32 (PD2)
/LM317_OUT: R8.1, U2.2 (VO)
/MEAS_NODE: J3.1, JTP9.1, R1.1, R8.2, R20.1, U2.1 (ADJ)
/MISO: J4.1 (MISO), U1.16 (PB4)
/MOSI: J4.4 (MOSI), U1.15 (PB3)
/RESET: J4.5 (~RST), JTP8.1, R10.1, U1.29 (~RESET/PC6)
/SCK: J4.3 (SCK), U1.17 (PB5)
/START_BTN: C8.1, SW1.1, U1.25 (PC2)
/USB_5V: J1.1 (VBUS), JTP1.1, Q1.2 (S), R2.1
GND: C1.1, C2.1, C3.1, C4.1, C5.1, C6.2, C7.1, C8.2, D1.1 (K), D2.1 (K), J1.5 (GND), J1.6 (Shield), J2.1, J3.2, J4.6 (GND), JTP5.1, Q2.2 (S), R3.2, R9.2, SW1.2, U1.3 (GND), U1.5 (GND), U1.21 (GND)
unnamed: D1.2 (A), R6.2
unnamed: D2.2 (A), R7.2
unnamed: Q1.1 (G), R2.2, R3.1
unnamed: Q2.3 (D), R20.2
unnamed: C2.2, U1.20 (AREF)
unnamed: C6.1, U1.7 (XTAL1/PB6), Y1.2
unnamed: C7.2, U1.8 (XTAL2/PB7), Y1.1

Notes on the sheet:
ANALOG
POWER/LOAD
DIGITAL
DNP

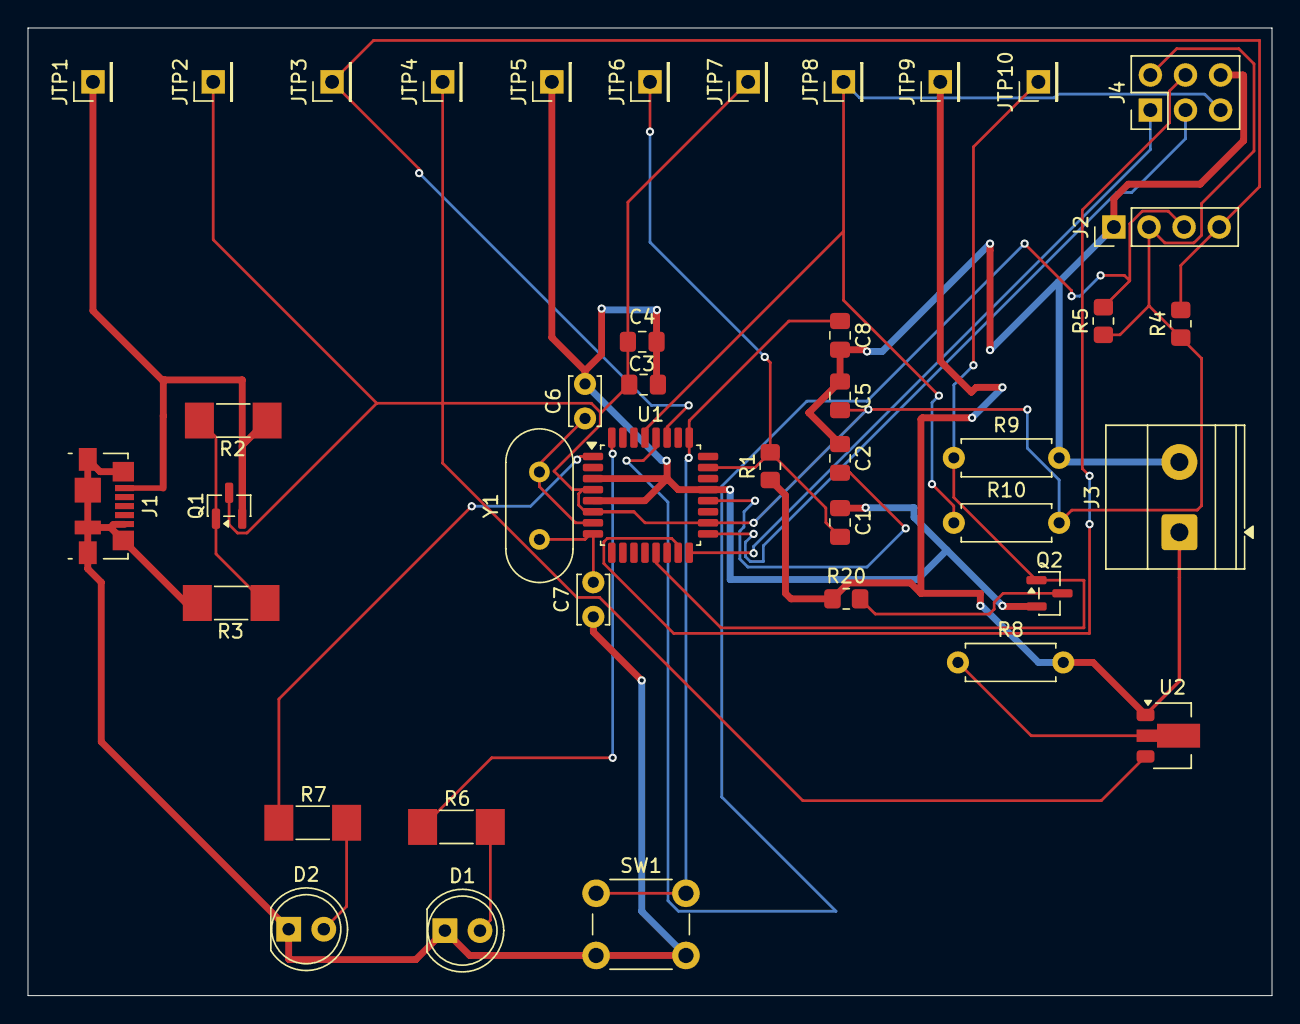
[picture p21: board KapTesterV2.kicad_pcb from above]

Board: 2 copper layers, 90.0 x 70.0 mm, 41 parts (0 on the bottom side), 23 nets.

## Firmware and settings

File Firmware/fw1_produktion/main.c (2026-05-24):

/*
 * ╔══════════════════════════════════════════════════════════════════════╗
 * ║   KapTester V2  —  Firmware 1: Produktion / "Light" (FINAL V1.5)     ║
 * ║   Hardware-Plattform: ATmega328P-AU @ 16.000 MHz (externer Quarz)    ║
 * ║   Anwendungsbereich: Schnelle Einzelmessung mit Hardware-Kompensation║
 * ║   Autor: Nico Schmidt  |  AP2-Abschlussprojekt                       ║
 * ╚══════════════════════════════════════════════════════════════════════╝
 *
 * ── PROFESSIOnELLE PROJEKT-HISTORIE & FEHLERKORREKTUR (WICHTIG FÜR DOKU) ──
 * * PROBLEM IN FIRMWARE-VERSION 1:
 * Der Entladewiderstand R20 (470 Ohm) bildet zusammen mit den Schutzdioden 
 * und dem Innenwiderstand des Entlade-Pfads einen Spannungsteiler. Der 
 * Kondensator (DUT) entlud sich daher nicht auf 0V, sondern lief bei ca. 0,5V 
 * in ein physikalisches Gleichgewicht. Die alte Entladeschleife wartete auf 
 * einen ADC-Wert < 5, was mathematisch unerreichbar war. Folge: Ein harter 
 * 5000 ms Timeout blockierte das Gerät, und nach dem Abschalten des Entlade-
 * MOSFETs lud die Konstantstromquelle den Cap sofort wieder auf.
 *
 * SYSTEMATISCHE KORREKTUR IN DIESER VERSION (FW1):
 * 1. Anhebung der Abbruchschwelle in discharge_wait() auf ADC-Wert 470 (~0,5V).
 * Die Schleife bricht nun exakt dann ab, wenn das Gleichgewicht erreicht ist.
 * 2. Eliminierung künstlicher Delays nach der Entladung, um ein unkontrolliertes
 * Wiederaufladen vor dem Messstart zu verhindern.
 * 3. Mathematische Kompensation über die modifizierte physikalische Formel:
 * C = (I * t) / (U_ref - U_start). Die verbleibende Startspannung (U_start)
 * wird direkt nach dem Entladen gemessen und vom Ladeziel (U_ref) abgezogen.
 * Damit arbeitet das Messgerät trotz Hardware-Einschränkung hochpräzise!
 */

#include <avr/io.h>
#include <avr/interrupt.h>
#include <util/delay.h>
#include <stdio.h>
#include <stdint.h>
#include "i2c.h"
#include "ssd1306.h"

/* ═══════════════════════════════════════════════════════════════════════
 * METROLOGISCHE & PHYSIKALISCHE KONSTANTEN (KALIBRIERUNG)
 * ═══════════════════════════════════════════════════════════════════════ */
#define I_UA              1042UL  /* Eingeprägter Konstantstrom: 1,25V / 1200 Ohm = 1,042 mA */
#define U_REF_MV          1100UL  /* Interne Bandgap-Referenzspannung des ATmega328P in mV     */
#define TICK_US             16UL  /* Zeitauflösung: Timer1 Prescaler 256 bei 16MHz -> 16µs/Tick*/
#define ADC_THRESH          1020  /* Analoges Ladeende: ~1,1V (Kurz vor ADC-Vollschlag 1023)  */
#define TIMEOUT_OVF         300U  /* Sicherheits-Timeout: 300 Timer-Überläufe (~314 Sekunden)  */
#define DISCH_TIMEOUT_MS   5000U  /* Maximal zulässige Schutz-Entladezeit in Millisekunden    */
#define N_MEAS                3   /* Anzahl der Rohmessungen für das Filter-Array             */
#define PLAUS_PCT            15UL /* Plausibilitäts-Korridor für den mathematischen Filter (±15%)*/
#define CAP_MIN_NF        10000UL /* Untere Messbereichsgrenze laut Spezifikation: 10 µF      */
#define CAP_MAX_NF     10000000UL /* Obere Messbereichsgrenze laut Spezifikation: 10.000 µF   */

/* * ENTLADE-SCHWELLE (HARDWARE-FIX v2):
 * Repräsentiert das physikalische Spannungs-Gleichgewicht am Entladepfad (~0,5V).
 * Verhindert den Endlos-Timeout der Entladeschaltung.
 */
#define DISCH_ADC_THRESH    470   

/* ═══════════════════════════════════════════════════════════════════════
 * HARDWARE-ABSTRAKTION (GPIO-MAKROS NACH DATENBLATT)
 * ═══════════════════════════════════════════════════════════════════════ */
#define LED_GRN_ON()    (PORTD |=  (1<<PD2))  /* Grüne LED aktivieren (High-Pegel)  */
#define LED_GRN_OFF()   (PORTD &= ~(1<<PD2))  /* Grüne LED deaktivieren (Low-Pegel) */
#define LED_RED_ON()    (PORTD |=  (1<<PD3))  /* Rote LED aktivieren (High-Pegel)   */
#define LED_RED_OFF()   (PORTD &= ~(1<<PD3))  /* Rote LED deaktivieren (Low-Pegel)  */
#define DISCH_ON()      (PORTB |=  (1<<PB1))  /* Entlade-MOSFET durchschalten       */
#define DISCH_OFF()     (PORTB &= ~(1<<PB1))  /* Entlade-MOSFET sperren             */
#define BTN_PRESSED()   (!(PINC & (1<<PC2)))  /* Taster gegen Masse abfragen (Low-aktiv) */

/*
 * MAKRO: ANALOG-DIGITAL-WANDLER RESTAURIEREN
 * Setzt die ADC-Register auf Standardkonfiguration: Interne 1,1V Referenz,
 * Aktivierung des ADC und Einstellen des Vorteilers auf 128 (16MHz / 128 = 125kHz Wandlertakt).
 * Dies garantiert maximale Wandlungspräzision im thermodynamischen Optimum.
 */
#define ADC_RESTORE() do {                                        \
    ADMUX  = (1<<REFS1) | (1<<REFS0);                            \
    ADCSRA = (1<<ADEN)|(1<<ADPS2)|(1<<ADPS1)|(1<<ADPS0);         \
} while(0)

/* ═══════════════════════════════════════════════════════════════════════
 * GLOBALER HARDWARE-TIMERSTATI (VOLATILE FÜR ISR-ZUGRIFF)
 * ═══════════════════════════════════════════════════════════════════════ */
volatile uint16_t ovf_count = 0; /* Zählt die Hardware-Überläufe von Timer1 (16-Bit) */
volatile uint8_t  ovf_flag  = 0; /* Globales Software-Flag für harten Timeout-Abbruch */

/*
 * TIMER1 ÜBERLAUF INTERRUPT SERVICE ROUTINE (ISR)
 * Wird automatisch aufgerufen, wenn Timer1 von 0xFFFF auf 0x0000 springt (alle 1,048 Sekunden).
 * Dient als asynchrone Zeitbasis für die Erkennung defekter oder kurzgeschlossener Kondensatoren.
 */
ISR(TIMER1_OVF_vect) {
    if (++ovf_count >= TIMEOUT_OVF) {
        ovf_flag = 1; /* Timeout-Grenze erreicht, Ladevorgang wird abgebrochen */
    }
}

/* ═══════════════════════════════════════════════════════════════════════
 * LOW-LEVEL HARDWARE-TREIBERFUNKTIONEN
 * ═══════════════════════════════════════════════════════════════════════ */

// GPIO-Richtungsregister initialisieren
void gpio_init(void) {
    DDRD |=  (1<<PD2) | (1<<PD3);  /* PD2 (LED_GRN) und PD3 (LED_RED) als Ausgang definieren */
    DDRB |=  (1<<PB1);             /* PB1 (DISCH_GATE) als digitalen Ausgang definieren       */
    DDRC &= ~((1<<PC2) | (1<<PC0));/* PC2 (Button) und PC0 (ADC-Messkanal) als Eingang       */
    PORTC |=  (1<<PC2);            /* Internen Pull-Up-Widerstand für den Taster aktivieren    */
    PORTC &= ~(1<<PC0);            /* Pull-Up für analogen Messkanal deaktivieren (hochohmig)  */
    LED_GRN_OFF(); LED_RED_OFF(); DISCH_OFF(); /* Sicheren Ausgangszustand erzwingen */
}

// Analog-Digital-Wandler initialisieren
void adc_init(void) {
    ADC_RESTORE();
    ADCSRA |= (1<<ADSC); /* Dummy-Wandlung starten, um die analoge Hardware einzuschwingen */
    while (ADCSRA & (1<<ADSC)); /* Warten, bis die Initialisierungswandlung abgeschlossen ist */
}

// Analogen Messwert synchron einlesen
uint16_t adc_read(void) {
    ADC_RESTORE();
    ADCSRA |= (1<<ADSC); /* Konvertierung auf Kanal ADC0 starten */
    while (ADCSRA & (1<<ADSC)); /* Bit-Polling: Warten, bis Wandlung fertig ist (ADSC wird 0) */
    return ADC; /* 10-Bit Digitalwert (0 bis 1023) zurückgeben */
}

// Hardware-Timer1 für präzise Zeitmessung konfigurieren und starten
void timer1_start(void) {
    ovf_count = 0; 
    ovf_flag = 0;
    TCNT1  = 0;          /* Timer-Zählerregister komplett nullen */
    TIFR1 |= (1<<TOV1);  /* Eventuell anhängige alte Überlauf-Flags löschen */
    TIMSK1 = (1<<TOIE1); /* Timer1 Overflow Interrupt lokal freischalten */
    TCCR1A = 0;          /* Normaler Modus, keine PWM-Ausgänge aktiv */
    TCCR1B = (1<<CS12);  /* Vorteiler (Prescaler) auf 256 setzen -> Startet den Timer quantisiert */
}

// Hardware-Timer1 stoppen und absolute Ticks berechnen
uint32_t timer1_stop(void) {
    uint16_t cnt = TCNT1;/* Zählerstand sofort sichern, um Latenzen zu minimieren */
    TCCR1B = 0;          /* Taktzufuhr stoppen (Timer steht still) */
    TIMSK1 = 0;          /* Interne Interrupts deaktivieren */
    /* Absolute Zeit berechnen: (Überläufe * 65536) + verbleibende Ticks */
    return (uint32_t)ovf_count * 65536UL + (uint32_t)cnt;
}

// Intelligente Sicherheitsentladung des Kondensators (Hardware-Fix v2 integriert)
void discharge_wait(void) {
    DISCH_ON(); /* Entlade-Pfad über MOSFET niederohmig schalten */
    for (uint16_t i = 0; i < DISCH_TIMEOUT_MS; i++) {
        _delay_ms(1);
        /* Abbruch, sobald die Entladeschwelle (Gleichgewicht bei ~0,5V) erreicht ist */
        if (adc_read() < DISCH_ADC_THRESH) break;
    }
    DISCH_OFF(); /* Entlade-Pfad isolieren, um die Messung nicht zu verfälschen */
}

/* ═══════════════════════════════════════════════════════════════════════
 * UI- & FORMATIERUNGS-HILFSFUNKTIONEN
 * ═══════════════════════════════════════════════════════════════════════ */

// Bereitet den statischen Begrüßungs-Bildschirm vor
void screen_ready(void) {
    ssd1306_clear();
    ssd1306_print(0, 0, " KapTester V2");
    ssd1306_print(0, 1, " -------------------");
    ssd1306_print(0, 3, " Status: BEREIT");
    ssd1306_print(0, 5, " Kondensator an-");
    ssd1306_print(0, 6, " schliessen...");
    ssd1306_print(0, 7, " [START] druecken");
}

// Formatiert den nF-Rohwert automatisch in ein lesbares µF- oder nF-Format
void format_cap(uint32_t nf, char *buf) {
    if (nf < 1000UL) {
        sprintf(buf, "%lu nF", nf); /* Werte unter 1000 nF direkt anzeigen */
    } else {
        uint32_t uf_int  = nf / 1000UL;       /* Ganzzahliger Anteil in µF */
        uint32_t uf_frac = (nf % 1000UL) / 10UL; /* Zwei Nachkommastellen extrahieren */
        sprintf(buf, "%lu.%02lu uF", uf_int, uf_frac);
    }
}

// Taktet die rote Fehler-LED für optische Warnungen
void led_blink_red(uint8_t n) {
    for (uint8_t i = 0; i < n; i++) {
        LED_RED_ON();  _delay_ms(150);
        LED_RED_OFF(); _delay_ms(150);
    }
}

/* ═══════════════════════════════════════════════════════════════════════
 * MATHEMATISCHER DATA-FILTER (ENTSTÖRUNG & PLAUSIBILITÄT)
 * ═══════════════════════════════════════════════════════════════════════ */

// Prüft, ob zwei Messwerte innerhalb des zulässigen Toleranzfensters (±15%) liegen
uint8_t plausible_pair(uint32_t a, uint32_t b) {
    uint32_t lo = (a < b) ? a : b;
    uint32_t hi = (a < b) ? b : a;
    if (lo == 0) return 0;
    /* Prozentuale Abweichung mathematisch ohne Fließkomma-Latenz prüfen */
    return ((hi - lo) * 100UL) <= (PLAUS_PCT * lo);
}

// 2-aus-3-Filter: Eliminiert statistische Ausreißer (z.B. durch Kontaktprellen)
uint32_t evaluate(uint32_t v[3]) {
    uint8_t p01 = plausible_pair(v[0], v[1]);
    uint8_t p02 = plausible_pair(v[0], v[2]);
    uint8_t p12 = plausible_pair(v[1], v[2]);

    /* Fall 1: Alle drei Messungen sind konsistent -> Arithmetischer Mittelwert */
    if (p01 && p02 && p12)   return (v[0] + v[1] + v[2]) / 3UL;
    /* Fall 2-4: Ein Wert streut massiv -> Ausreißer verwerfen, restliche 2 mitteln */
    if (p01 && !p12 && !p02) return (v[0] + v[1]) / 2UL;
    if (p02 && !p01 && !p12) return (v[0] + v[2]) / 2UL;
    if (p12 && !p01 && !p02) return (v[1] + v[2]) / 2UL;
    /* Fall 5: Totale Streuung -> Kein Wert passt zum anderen (Messung ungültig) */
    return 0; 
}

/* ═══════════════════════════════════════════════════════════════════════
 * ZENTRALE STEUERUNGSSCHLEIFE (MAIN EXECUTION LOOP)
 * ═══════════════════════════════════════════════════════════════════════ */
int main(void) {
    // Hardware-Subsysteme hochfahren
    gpio_init();
    adc_init();
    i2c_init();
    ssd1306_init();
    sei(); /* Globale Interrupt-Freigabe für die Timer-ISR */

    LED_GRN_ON();
    screen_ready();

    for (;;) {
        // Taster abfragen mit Software-Entprellung
        if (!BTN_PRESSED()) continue;
        _delay_ms(30); /* 30 ms Karenzzeit gegen mechanisches Tasterprellen */
        if (!BTN_PRESSED()) continue;

        // Visualisierung des Messstarts
        LED_GRN_OFF();
        LED_RED_ON();
        ssd1306_clear();
        ssd1306_print(0, 2, " Messung laeuft...");
        ssd1306_print(0, 4, " Bitte warten...");

        uint32_t vals[N_MEAS]; /* Array für die 3 mathematischen Einzelmessungen */
        uint8_t  timeout_any = 0;

        // Haupt-Messzyklus (3 Durchläufe für höchste Störsicherheit)
        for (uint8_t m = 0; m < N_MEAS; m++) {
            discharge_wait(); /* Kondensator kontrolliert entladen */

            /* * HARDWARE-COMPENSATION (Fix v2):
             	* Da der Kondensator bei ~0,5V verweilt, lesen wir diese verbleibende 
             	* Startspannung exakt JETZT ein, bevor die Stromquelle aktiv wird.
             	*/
            uint16_t u_start_adc = adc_read();
            /* Skalierung auf Millivolt: (ADC-Wert * 1100 mV) / 1023 Ticks */
            uint32_t u_start_mv  = (uint32_t)u_start_adc * U_REF_MV / 1023UL;
            
            /* Spannungs-Delta berechnen: Ladeziel (1,1V) minus realer Startpunkt */
            uint32_t u_delta_mv  = U_REF_MV - u_start_mv;

            // Plausibilitätsprüfung: Ist das Delta zu klein, bricht das System ab
            if (u_delta_mv < 50UL) {
                timeout_any = 1;
                break;
            }

            uint16_t adc_val = 0;
            timer1_start(); /* Präzise Zeitmessung starten */

            /* * ABSOLUTES POLLING IM TEMPORAUSCH:
             	* Die CPU fokussiert sich zu 100% auf das Einlesen des ADC-Werts. 
             	* Keine Display-Ausgaben oder Delays stören diesen zeitkritischen Prozess!
             	*/
            do {
                adc_val = adc_read();
                if (ovf_flag) break; /* Notabschaltung bei Timeout-Flag aus der ISR */
            } while (adc_val < ADC_THRESH);

            uint32_t ticks = timer1_stop(); /* Zeitmessung stoppen und Ticks sichern */

            // Validierung, ob der Zyklus regulär beendet wurde
            if (ovf_flag || adc_val < ADC_THRESH) {
                timeout_any = 1;
                break;
            }

            /*
             	* PHYSIKALISCHE FORMELBERECHNUNG (C = I * t / dU):
             	* tmp = Strom (µA) * Zeitauflösung (µs/Tick) * gemessene Ticks
             	* Das Ergebnis liefert direkt die exakte Kapazität in Nano-Farad (nF).
             	*/
            uint64_t tmp = (uint64_t)I_UA * (uint64_t)TICK_US * (uint64_t)ticks;
            vals[m] = (uint32_t)(tmp / u_delta_mv);
            
            _delay_ms(10); /* Kurze thermische Beruhigungspause für die Hardware */
        }

        // FEHLERBEHANDLUNG: Timeout-Fall (Kein Bauteil oder Kurzschluss)
        if (timeout_any) {
            ssd1306_clear();
            ssd1306_print(0, 1, "   ** TIMEOUT **");
            ssd1306_print(0, 3, " Messfehler oder");
            ssd1306_print(0, 4, " kein Kondensator");
            ssd1306_print(0, 5, " detektiert!");
            led_blink_red(5);
            discharge_wait();
            LED_GRN_ON();
            screen_ready();
            continue;
        }

        // Mathematische Ausreißer-Filterung anwenden
        uint32_t result = evaluate(vals);

        // FEHLERBEHANDLUNG: Instabile Werte (Rauschen oder Kontaktproblem)
        if (result == 0) {
            char b0[16], b1[16], b2[16];
            format_cap(vals[0], b0);
            format_cap(vals[1], b1);
            format_cap(vals[2], b2);

            ssd1306_clear();
            ssd1306_print(0, 0, "   ** FAIL **");
            ssd1306_print(0, 2, "Werte streuen:");
            ssd1306_print(0, 3, b0);
            ssd1306_print(0, 4, b1);
            ssd1306_print(0, 5, b2);
            ssd1306_print(0, 7, "Kontakt pruefen");
            led_blink_red(6);
            LED_RED_ON();
            _delay_ms(3000);
            LED_RED_OFF();
            discharge_wait();
            LED_GRN_ON();
            screen_ready();
            continue;
        }

        // ERFOLGREICHE MESSUNG: Grenzwert-Überwachung & Ausgabe
        char cap_str[20];
        format_cap(result, cap_str);

        uint8_t out_of_range = 0;
        const char *range_warn = "";

        // Plausibilitäts-Check gegen das offizielle Datenblatt
        if (result < CAP_MIN_NF) {
            out_of_range = 1;
            range_warn   = "Warnung: < 10uF!";
        } else if (result > CAP_MAX_NF) {
            out_of_range = 1;
            range_warn   = "Warnung: > 10mF!";
        }

        // Endergebnis auf dem OLED-Display ausgeben
        ssd1306_clear();
        ssd1306_print(0, 0, " KapTester V2");
        ssd1306_print(0, 2, "Ergebnis:");
        ssd1306_print(0, 3, cap_str);

        if (out_of_range) {
            ssd1306_print(0, 5, range_warn);
            ssd1306_print(0, 6, "Ausserhalb Spec!");
            LED_RED_ON(); /* Rote LED warnt vor Spezifikationsverletzung */
        } else {
            ssd1306_print(0, 5, "Messung gueltig");
            ssd1306_print(0, 6, "Toleranz geprueft");
            LED_GRN_ON(); /* Grüne LED signalisiert Erfolg */
        }
        
        // System hält das Ergebnis für 5 Sekunden statisch im Display
        _delay_ms(5000);
        
        // Nachbereitung für den nächsten Zyklus
        LED_GRN_OFF();
        LED_RED_OFF();
        discharge_wait(); /* Sicherheitsentladung nach der Messung */
        LED_GRN_ON();
        screen_ready();   /* Zurück in den Bereit-Modus */
    }
    return 0;
}

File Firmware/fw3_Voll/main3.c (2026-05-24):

/*
 * ╔══════════════════════════════════════════════════════════════════════╗
 * ║   KapTester V2  —  Firmware 3: Komplettpaket (FINAL V3.5)           ║
 * ║   Hardware-Plattform: ATmega328P-AU @ 16.000 MHz (externer Quarz)    ║
 * ║   Zweck: High-End Firmware mit dynamischem UI-Filter & Statistik     ║
 * ║   Autor: Nico Schmidt  |  AP2-Abschlussprojekt                       ║
 * ╚══════════════════════════════════════════════════════════════════════╝
 *
 * ── ARCHITEKTUR-HIGHLIGHTS & PROJEKT-INNOVATIONEN (FÜR DEINE DOKU) ──────
 * 1. ASYNCHRONES "KINO-TIMING" (FLACKERFREIE ANIMATION):
 * Um das OLED-Display flüssig zu animieren, ohne die zeitkritische Hardware-
 * Zeitmessung zu stören, sind UI und Messung strikt entkoppelt. Das Display 
 * wird *vor* und *nach* den reinen Messphasen aktualisiert. Während der 
 * eigentlichen Erfassung schaltet die CPU in den "Temporausch" (reines Polling).
 *
 * 2. DYNAMISCHES UPSCALING BEI GIGANTISCHEN KAPAZITÄTEN:
 * Große Elektrolytkondensatoren (> 1 mF) laden sich physikalisch träge auf. 
 * Damit die Software-Animation zur Realität passt, dehnt die Firmware die 
 * Animationsschritte automatisch von 220 ms auf 450 ms aus (hervorragende UX).
 *
 * 3. VOLATILE SESSION-STATISTIK (QUALITÄTSKONTROLLE):
 * Ein integrierter Ringpuffer und Extremwertspeicher trackt die Messungen einer 
 * Prüfserie (Passed, Failed, Max, Min). Damit mutiert das Gerät zum echten 
 * Labor-Messplatz.
 *
 * 4. MULTI-CLICK-ZUSTANDSMASCHINE:
 * Ein softwarebasierter Klick-Zähler analysiert das Zeitfenster (350 ms) nach 
 * der ersten Flanke und unterscheidet sauber zwischen Einzelklick (Messung), 
 * Doppelklick (Statistik-Menü) und Fünffachklick (Diagnose-Modus / Disco).
 */

#include <avr/io.h>
#include <avr/interrupt.h>
#include <util/delay.h>
#include <stdio.h>
#include <stdint.h>
#include "i2c.h"
#include "ssd1306.h"

/* ═══════════════════════════════════════════════════════════════════════
 * METROLOGISCHE & PHYSIKALISCHE KONSTANTEN (KALIBRIERUNG)
 * ═══════════════════════════════════════════════════════════════════════ */
#define I_UA              1042UL  /* Eingeprägter Konstantstrom: 1,25V / 1200 Ohm = 1,042 mA */
#define U_REF_MV          1100UL  /* Interne Bandgap-Referenzspannung des ATmega328P in mV     */
#define TICK_US             16UL  /* Zeitauflösung: Timer1 Prescaler 256 bei 16MHz -> 16µs/Tick*/
#define ADC_THRESH          1020  /* Analoges Ladeende: ~1,1V (Kurz vor ADC-Vollschlag 1023)  */
#define TIMEOUT_OVF         300U  /* Sicherheits-Timeout: 300 Timer-Überläufe (~314 Sekunden)  */
#define DISCH_TIMEOUT_MS   5000U  /* Maximal zulässige Schutz-Entladezeit in Millisekunden    */
#define N_MEAS                3   /* Anzahl der Rohmessungen für das Filter-Array             */
#define PLAUS_PCT            15UL /* Plausibilitäts-Korridor für den mathematischen Filter (±15%)*/
#define CAP_MIN_NF        10000UL /* Untere Messbereichsgrenze laut Spezifikation: 10 µF      */
#define CAP_MAX_NF     10000000UL /* Obere Messbereichsgrenze laut Spezifikation: 10.000 µF   */

/* * INTEGRATION DES HARDWARE-FIXES (v2):
 * Erzwungenes Abbruchkriterium der Entladeschleife, wenn das physikalische
 * Gleichgewicht am Spannungsteiler (~0,5V) erreicht ist. Verhindert Deadlocks.
 */
#define DISCH_ADC_THRESH    470   
#define U_START_MIN_MV       50UL /* Mindestrestspannung für mathematischen Unterlauf-Schutz */

/* ═══════════════════════════════════════════════════════════════════════
 * ERGONOMISCHE UI- UND INTERFACE-PARAMETER
 * ═══════════════════════════════════════════════════════════════════════ */
#define CLICK_WINDOW_MS     350U  /* Zeitfenster für die Multi-Click-Erkennung (in ms)     */
#define DISCO_FRAME_MS      200U  /* Animationsgeschwindigkeit im Diagnose-Oszillator      */
#define GREEN_FLASH_MS       60U  /* Taktzeit für akustisches/visuelles Benutzerfeedback  */
#define BAR_INNER            14   /* Anzahl der inneren Segmente des Ladebalkens           */
#define BOOT_STEPS           14   /* Anzahl der Schritte für die Boot-Animation            */
#define BOOT_STEP_MS         280U  /* Zeit pro Boot-Inkrement (Insgesamt ca. 4 Sekunden)    */
#define DISCH_HOLD_MS       400U  /* Erzwungene Mindestanzeigezeit der Entladewarnung      */

/* ═══════════════════════════════════════════════════════════════════════
 * HARDWARE-ABSTRAKTION (GPIO-MAKROS NACH REINEM REGISTER-C)
 * ═══════════════════════════════════════════════════════════════════════ */
#define LED_GRN_ON()    (PORTD |=  (1<<PD2))  /* Grüne LED ein (Messung valide / Bereit) */
#define LED_GRN_OFF()   (PORTD &= ~(1<<PD2))  /* Grüne LED aus                           */
#define LED_GRN_TOG()   (PORTD ^=  (1<<PD2))  /* Toggelt den Zustand (wichtig für Balken)*/
#define LED_RED_ON()    (PORTD |=  (1<<PD3))  /* Rote LED ein (Entladung / Fehler)      */
#define LED_RED_OFF()   (PORTD &= ~(1<<PD3))  /* Rote LED aus                            */
#define DISCH_ON()      (PORTB |=  (1<<PB1))  /* Aktiviert den Entlade-MOSFET            */
#define DISCH_OFF()     (PORTB &= ~(1<<PB1))  /* Isoliert den Entlade-MOSFET             */
#define BTN_PRESSED()   (!(PINC & (1<<PC2)))  /* Low-aktiver Taster (gegen interne Masse)*/

/* registerspezifische Makro-Restauration für den ADC */
#define ADC_RESTORE() do {                                        \
    ADMUX  = (1<<REFS1) | (1<<REFS0);                            \
    ADCSRA = (1<<ADEN)|(1<<ADPS2)|(1<<ADPS1)|(1<<ADPS0);         \
} while(0)

/* ═══════════════════════════════════════════════════════════════════════
 * ASYNCHRONER HARDWARE-ZEITGEBER & STATISTIK-SPEICHER
 * ═══════════════════════════════════════════════════════════════════════ */
volatile uint16_t ovf_count = 0; /* Interrupt-Zähler für Timer1-Überläufe */
volatile uint8_t  ovf_flag  = 0; /* Globales Abbruchflag für Timeout-Erkennung */

// Asynchrone Interrupt-Überwachung (wird alle 1,048 Sekunden getriggert)
ISR(TIMER1_OVF_vect) {
    if (++ovf_count >= TIMEOUT_OVF) ovf_flag = 1;
}

/* Statische Variablen (behalten ihren Wert über die gesamte Laufzeit / Session) */
static uint16_t ses_passed = 0;          /* Zähler für erfolgreiche Messungen */
static uint16_t ses_failed = 0;          /* Zähler für fehlerhafte Zyklen      */
static uint16_t ses_total  = 0;          /* Gesamtzahl aller gestarteten Tests */
static uint32_t ses_max_nf = 0;          /* Maximalwert der aktuellen Session  */
static uint32_t ses_min_nf = 0xFFFFFFFFUL;/* Minimalwert der aktuellen Session  */
static uint8_t  ui_mode    = 0;          /* 0 = Hauptmenü, 1 = Stats 1, 2 = Stats 2 */

/* ═══════════════════════════════════════════════════════════════════════
 * PERIPHERIE-TREIBER (LOW-LEVEL CONTROL)
 * ═══════════════════════════════════════════════════════════════════════ */

static void gpio_init(void) {
    DDRD |=  (1<<PD2) | (1<<PD3);
    DDRB |=  (1<<PB1);
    DDRC &= ~((1<<PC2) | (1<<PC0));
    PORTC |=  (1<<PC2);
    PORTC &= ~(1<<PC0);
    LED_GRN_OFF(); LED_RED_OFF(); DISCH_OFF();
}
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
